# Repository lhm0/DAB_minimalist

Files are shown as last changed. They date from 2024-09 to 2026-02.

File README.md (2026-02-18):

# Minimalist DAB+ radio for the visually impaired

## Abstract: 
An easy to use DAB+ radio for the visually impaired. The radio is configured once using an intuitive web interface. Key components of the device are an Arduino D1 R32 microprocessor board and a DABshield board for radio reception. The radio is very easy to replicate. Full documentation is available on GitHub.

<p align="center"> 
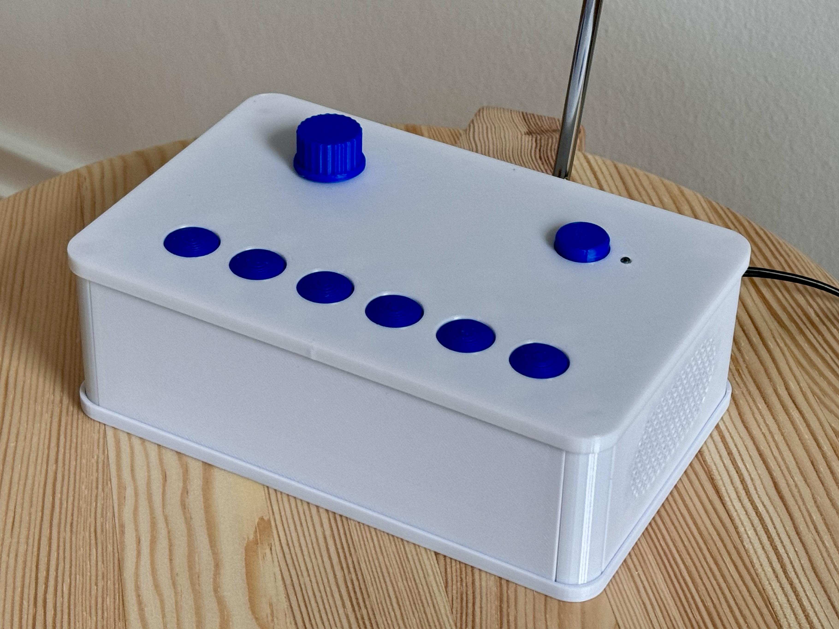
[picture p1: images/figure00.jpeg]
  
</p>

<p align="center"> 
<a href="https://youtu.be/GW8XSlcxrfo" target="_blank">
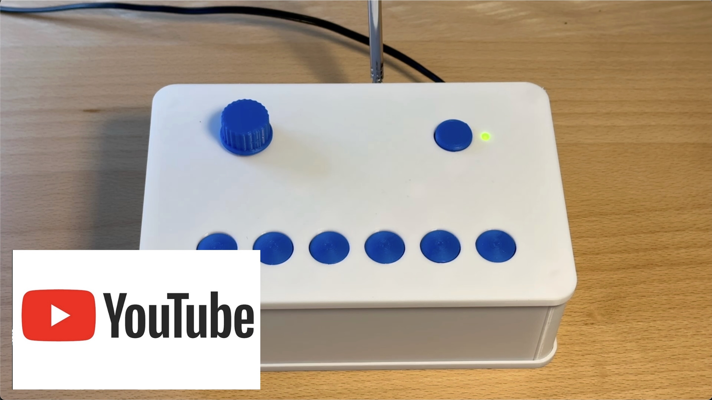
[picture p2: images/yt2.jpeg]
  
</a>
</p> 

## Part of an Accessible Devices Collection

This repository is part of a small collection of **minimalistic, accessibility-focused devices for visually impaired users**. All projects follow a similar philosophy: simple operation, tactile or acoustic feedback, and a strong focus on usability and low power consumption.

The currently available devices in this collection are:

- **[DAB+ Radio](https://github.com/lhm0/DAB_minimalist)** – This project: a minimalist, easy-to-use DAB+ radio  
- **[Talking Clock](https://github.com/lhm0/talking_clock)** – A clock that announces the time acoustically  
- **[Accessible IR Remote Control](https://github.com/lhm0/accessible_ir_remote)** – A tactile, low-power TV remote control  

All projects are designed to be practical, easy to reproduce, and suitable for everyday use by visually impaired users.

## 1. The idea
The radio was developed for a elderly visually impaired lady. The idea was to make the device as easy to use as possible. The preferred radio stations were to be selected once from the large number of DAB+ stations and assigned to 6 station buttons. In addition to these buttons, the on/off switch and the volume control should also be easy to reach with large buttons. A display has been omitted.

<p align="center"> 
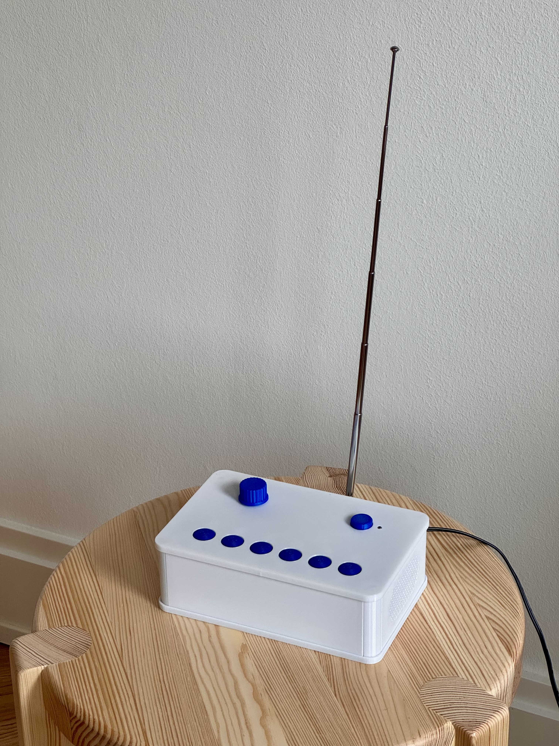
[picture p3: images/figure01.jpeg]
  
</p>

**Figure 1:  Minimalist DAB+ radio.** An easy to use DAB+ radio (not only) for visually impaired.

## 2. Description of the device

Digital Audio Broadcasting (DAB) is a digital radio standard being used predominatly in Europe, but also in Australia, and in parts of Africa and Asia [(Wikipedia)](https://en.wikipedia.org/wiki/Digital_Audio_Broadcasting).

The described radio is based on the DAB+ module [“DABshield”](https://www.dabshield.com), which is controlled by an Arduino microcontroller board “D1 R32”. It has the UNO form factor and can interface with UNO shields. The ESP32 microcontroller monitors 6 station buttons and the volume control. It also has a WiFi module for remote control of the radio.

The radio is housed in a 3D-printed housing (**figure 2**). All mechanical parts were designed with Fusion 360. The electronics are mounted on a carrier PCB (KiCAD). The microcontroller module and the “DABshield” are plugged on top of each other. The switches for the control of the device are also soldered onto the carrier board. This makes the radio easy and uncomplicated to replicate.

<p align="center"> 
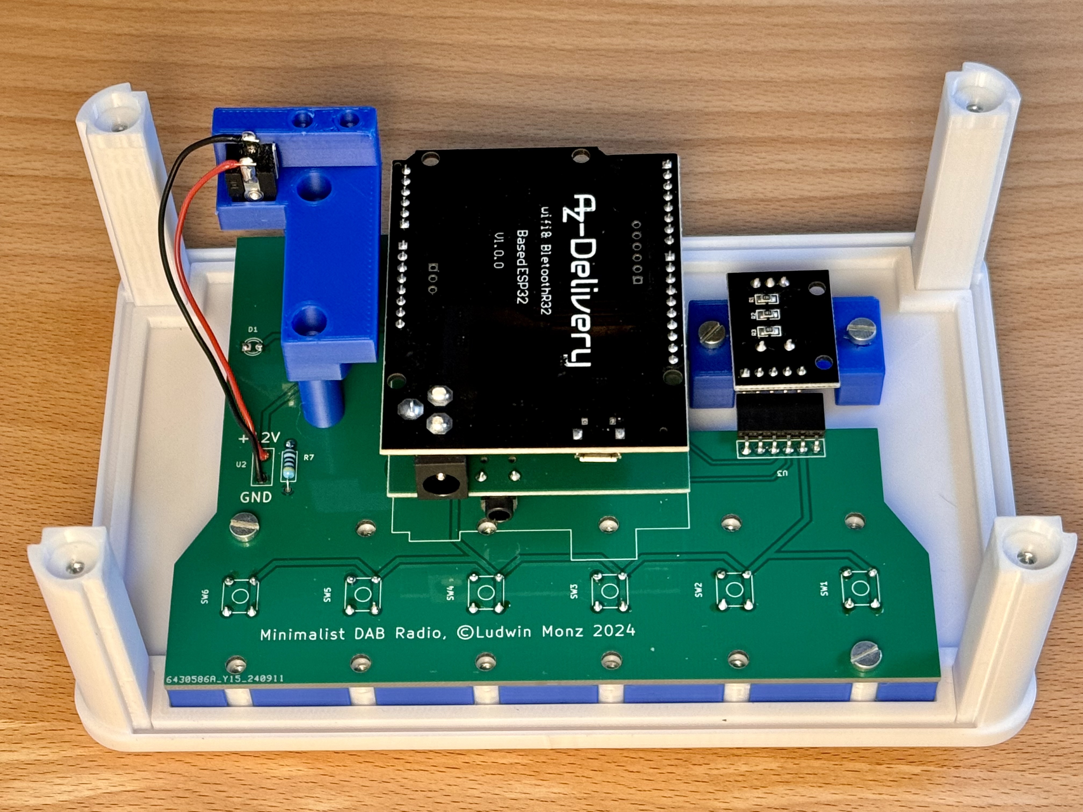
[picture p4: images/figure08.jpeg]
  
</p>
<p align="center"> 
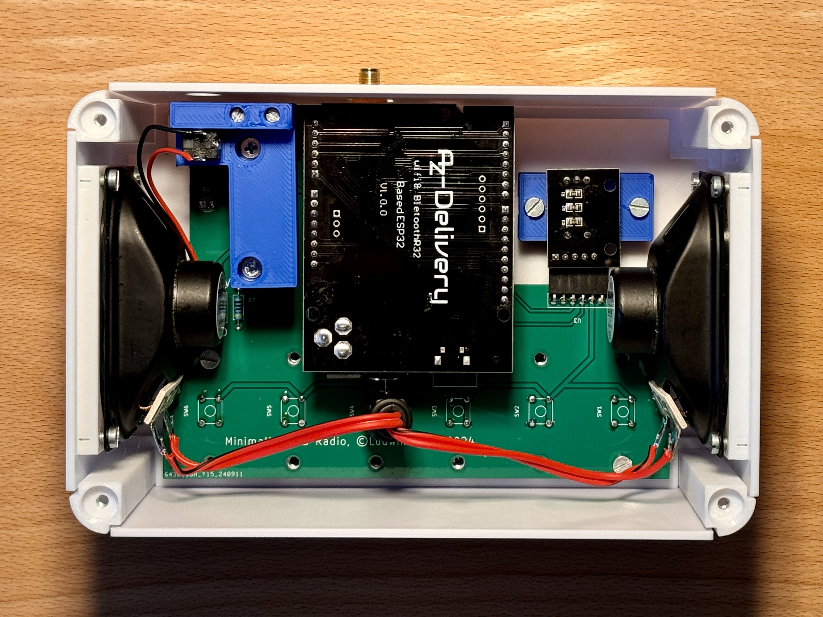
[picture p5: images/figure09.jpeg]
  
</p>

**Figure 2:  Mechnical setup of the radio.** The top cover serves as chassis of the device. All electronics components are connected through a carrier PCB.

## 3. Operation of the Device and initial setup

The user interface has been reduced to a minimum. In addition to the on/off switch and a volume control, it only consists of 6 station buttons. As the radio is intended for the visually impaired, the haptics of the controls are important.

All settings of the radio, i.e. the programming of the station buttons, the selected station and the volume, are stored in the flash memory of the microcontroller. They are immediately available when the device is switched on.

To program the station buttons in the initial setup, the device is connected to a cell phone or computer via a WiFi connection. If no connection data (SSID and password) of a WiFi network has been stored, the device switches to “Access Point Mode” when it is switched on. In this operating mode, a WiFi network with the SSID “mini_DAB” is created. You can connect to this network without using a password. The user interface is called up with a web browser by entering the address “192.168.4.1” in the address field of the browser.

<p align="center"> 
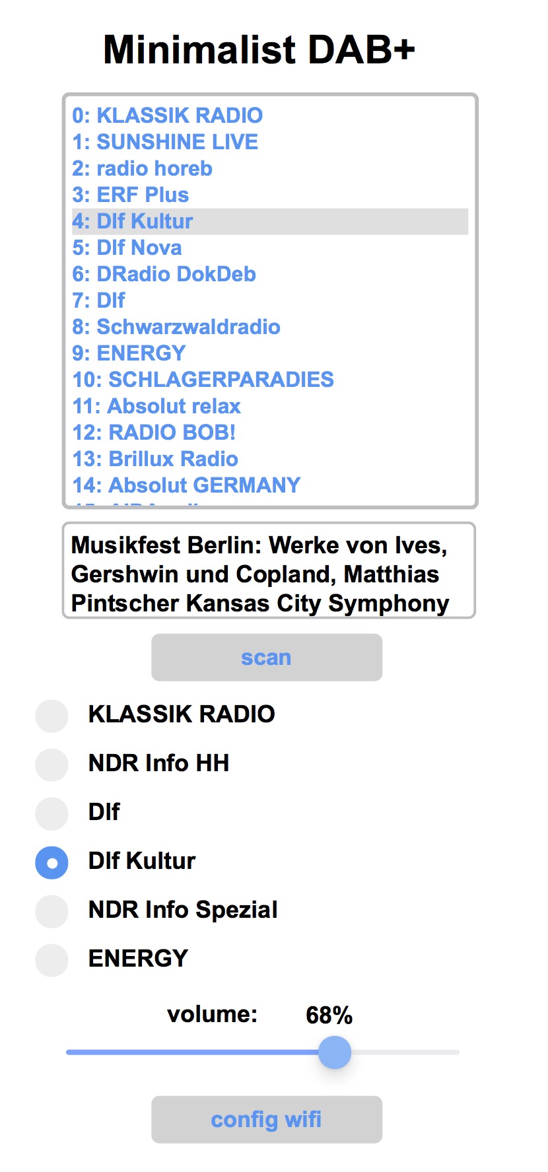
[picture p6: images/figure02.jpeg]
  
</p>

**Figure 3:** The **web user interface** allows for device configuration.

The setup screen displays a scrollable list of available DAB+ radio stations. If you select an entry, the radio tunes to the station. Below the station list, the continuous text information of the selected station is displayed.

If the location of the radio has been changed, it is advisable to start a new station search. To do this, click on the corresponding button. The saved station list and the selected assignment of the station buttons will then be deleted. The new station list is automatically saved in the flash memory.

There are 6 assignable station buttons further down. These correspond to the 6 physical buttons on the radio. To assign a station to the buttons, first select it in the station list. Then click and hold on one of the station buttons. The station is then saved for this button.
The volume can also be changed via the website.

As soon as you leave the setup page, the radio works independently with the preset parameters.

## 4. Replicating the radio
All housing parts are 3D printed (**figure 4**). The design data and STL files are available in the GitHub repository. M2 and M3 nuts are inserted into some parts for the mechanical connection of the parts. To insert the nuts, the 3D print must be paused at the correct point in time (**figure5**).

<p align="center"> 
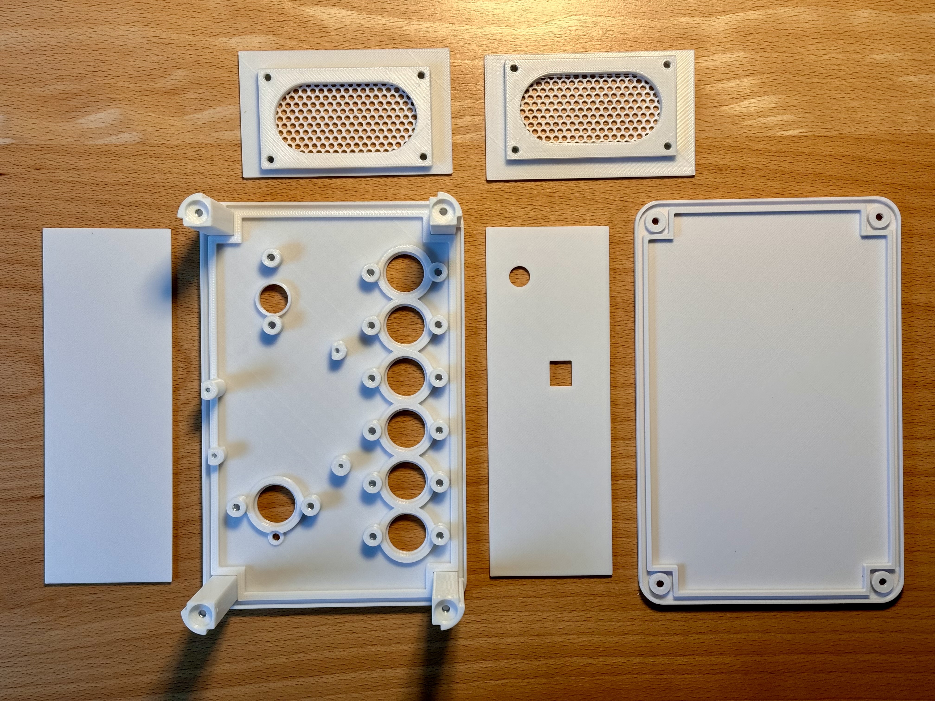
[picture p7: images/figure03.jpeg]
  
</p>
<p align="center"> 
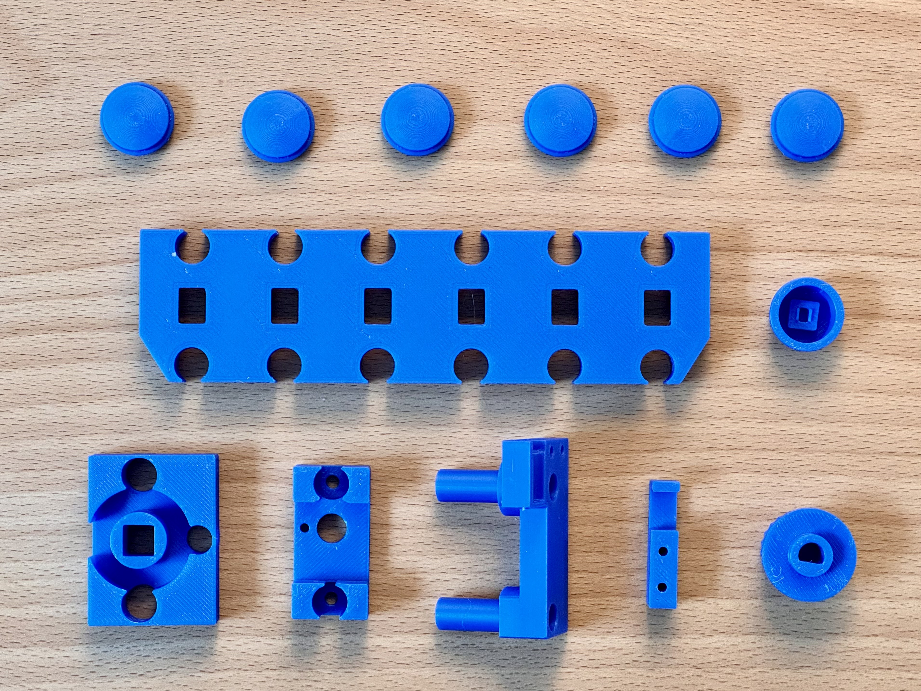
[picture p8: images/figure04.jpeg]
  
</p>

**Figure 4: Mechanical parts of the Minimalist DAB+ Radio.** All parts are 3D printed.

<p align="center"> 
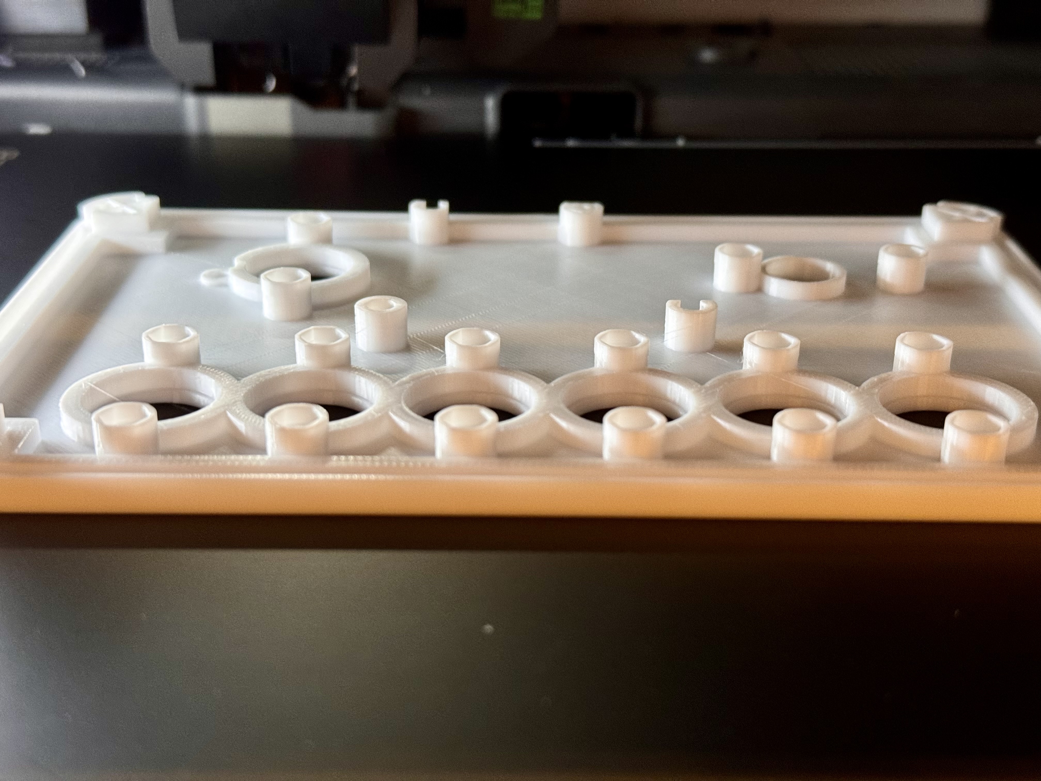
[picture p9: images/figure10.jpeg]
  
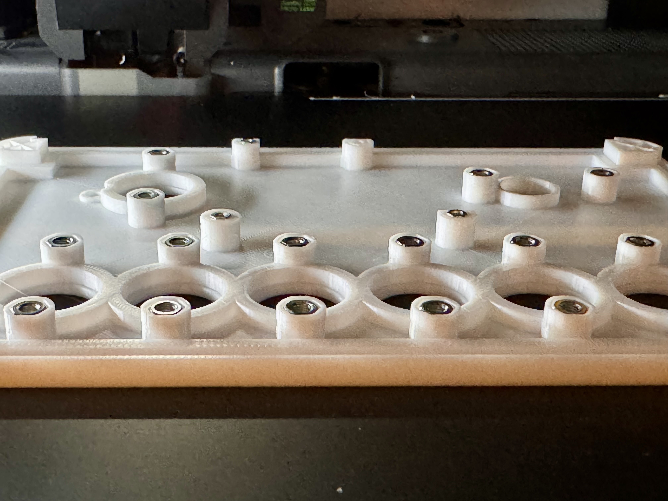
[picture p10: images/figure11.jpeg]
  
</p>

**Figure 5: M2 and M3 nuts need to be inserted into the 3D print**

The electronic components are off-the-shelf (**figure 6**). They are listed in the parts list. The only "single source component" is the DAB+ radio module 'DABshield', developed and marketed by the UK company AVIT Research Ltd. [(50 GBP + shipping and handling).](https://www.dabshield.com/store) This module is very reliable and easy to interface with and use.

The carrier board was designed with KiCAD. The project files including the production files are available in the GitHub repository. For the prototype, the board was manufactured by JLCPCB - however, there are numerous alternatives that offer very good quality for relatively little money.

<p align="center"> 
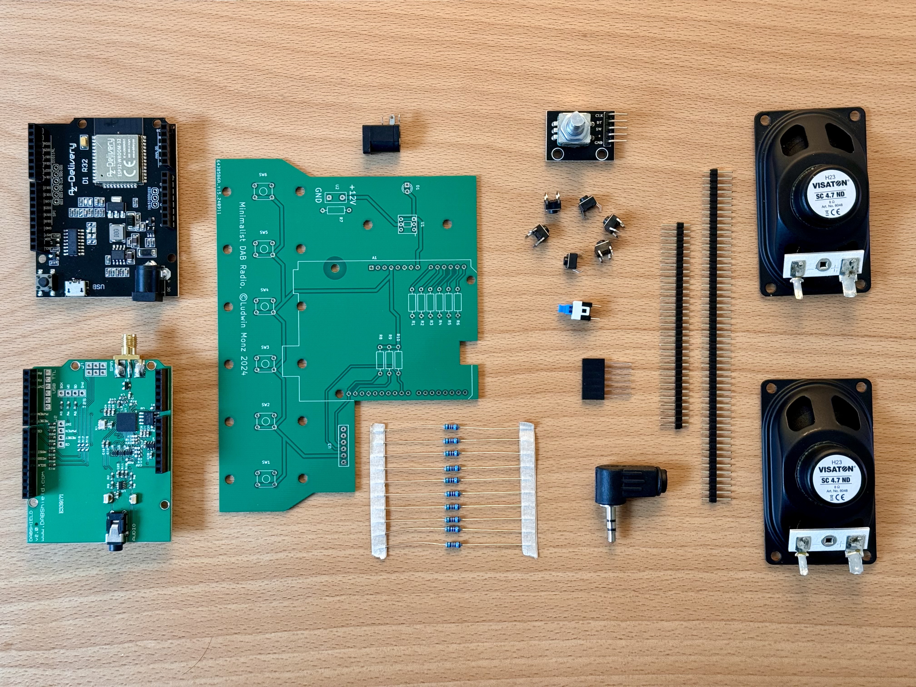
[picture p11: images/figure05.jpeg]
  
</p>

**Figure 6: The electronics components of the DAB+ Radio**

It is best to start assembling the device by fitting the carrier board. The switch, buttons and LED are mounted on the back of the board. The pin headers for connecting the DABshield and the microcontroller are positioned on the component side. The details can be found in the KiCAD design files. **Figure 7** shows the front and back of the board .

<p align="center"> 
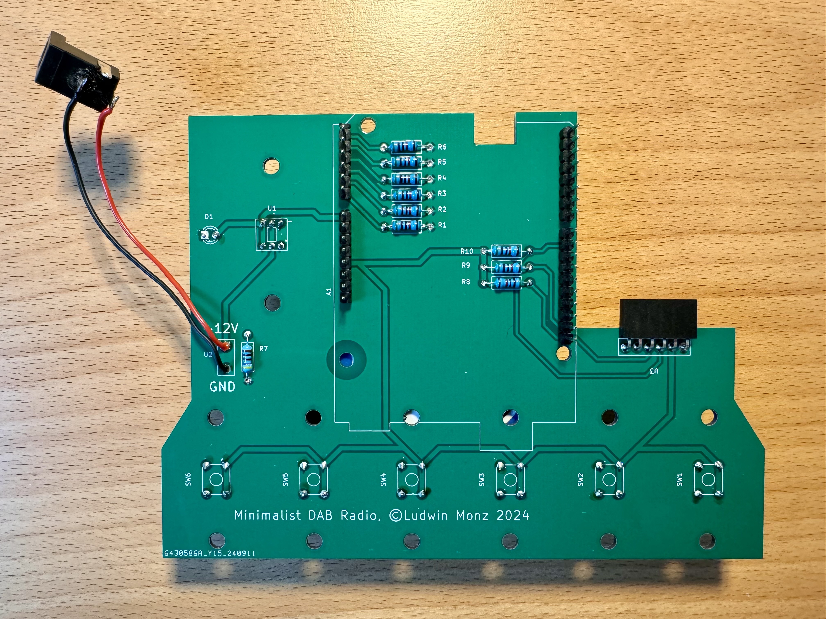
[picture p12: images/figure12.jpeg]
  
</p><p align="center"> 
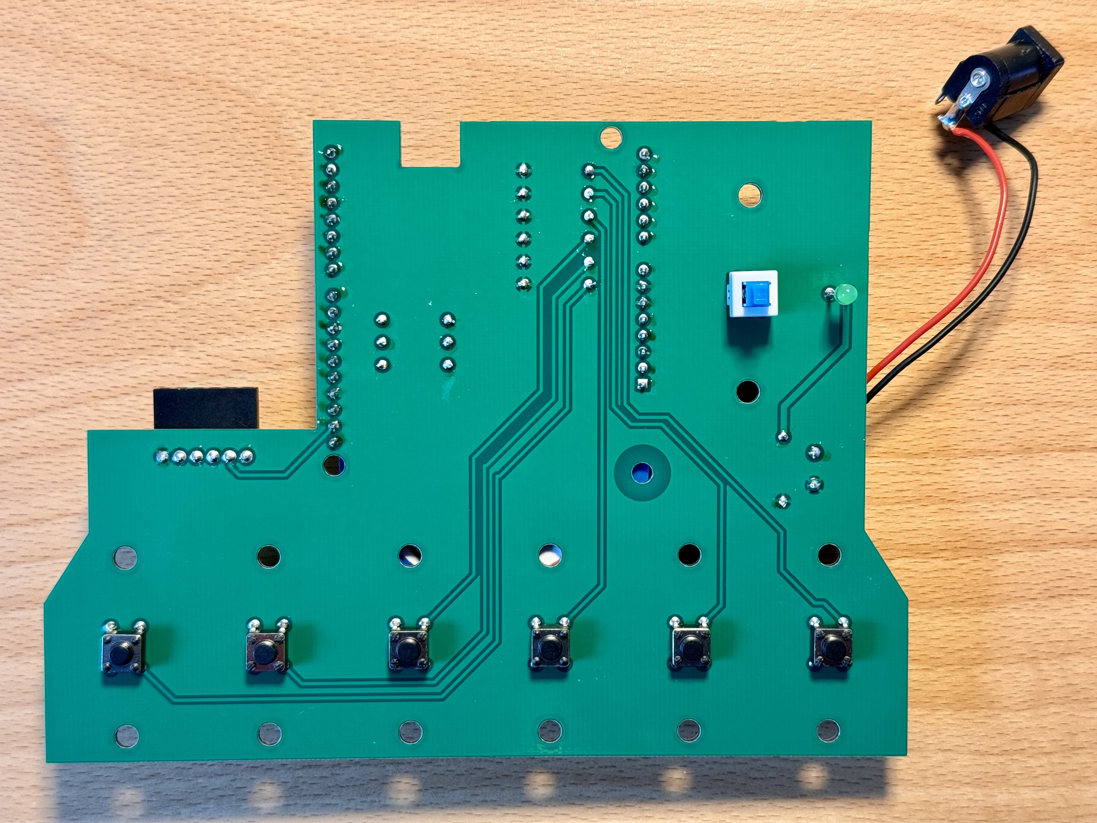
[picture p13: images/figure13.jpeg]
  
</p>

**Figure 7: Carrier PCB.** All switches and buttons are soldered to the back side, pin headers for the DABshield are on the component side.

The encoder for the volume setting is mounted on a carrier block. Note the correct position of the 5 pins of the module in the 6-pin socket (**figure 8**).

<p align="center"> 
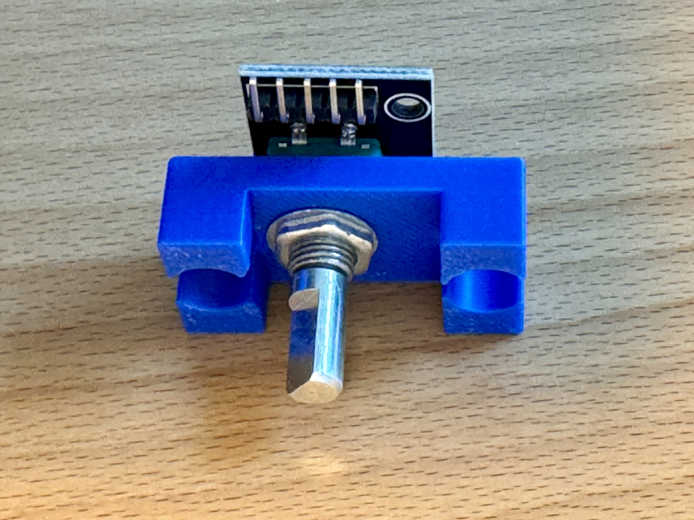
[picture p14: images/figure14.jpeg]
  
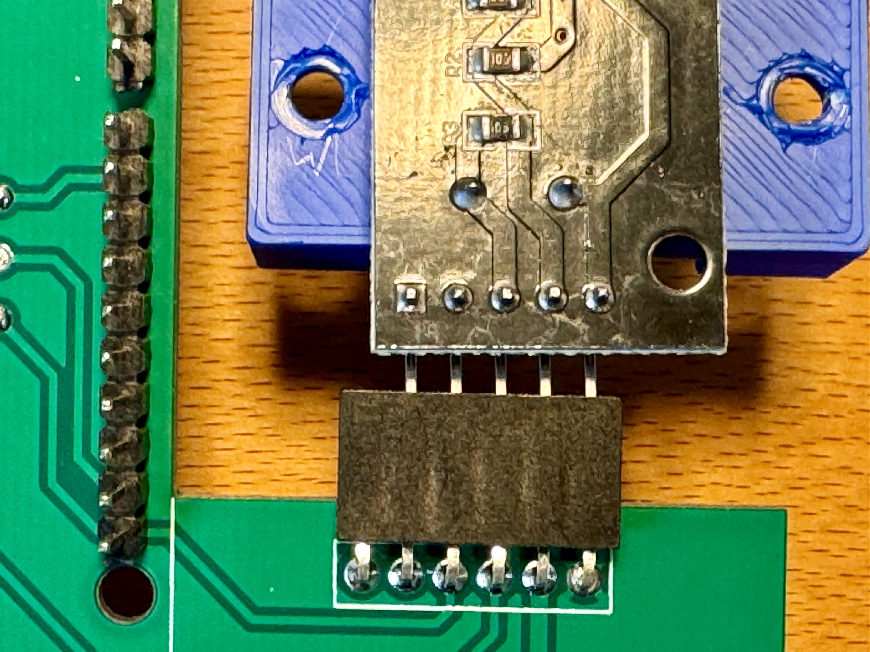
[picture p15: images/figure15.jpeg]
  
</p>

**Figure 8: Mounting of the encoder for volume control**

The two speakers are connected with a 3.5 mm jack plug. The common pole of the plug is the negative pole (**figure 9**).

<p align="center"> 
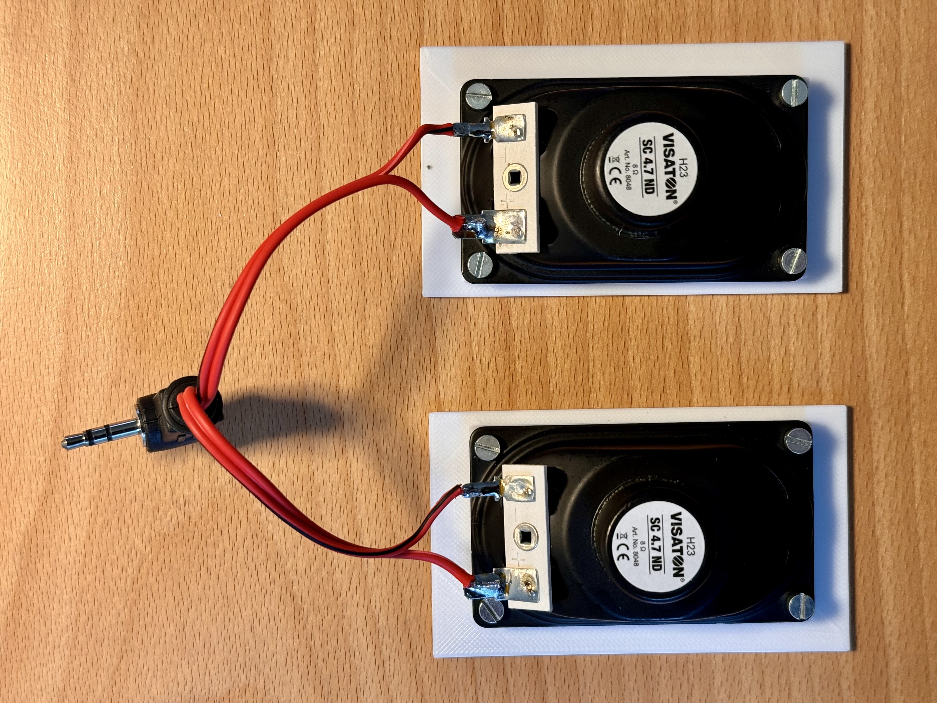
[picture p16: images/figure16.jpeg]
  
</p>

**Figure 9: Two speakers are connected to a 3.5 mm jack plug**

The successive steps for assembling the appliance are shown in Figure 10. The front cover can initially be removed to allow access to the micro-USB socket of the microcontroller module. In this way, the software can be loaded onto the module.

<p align="center"> 
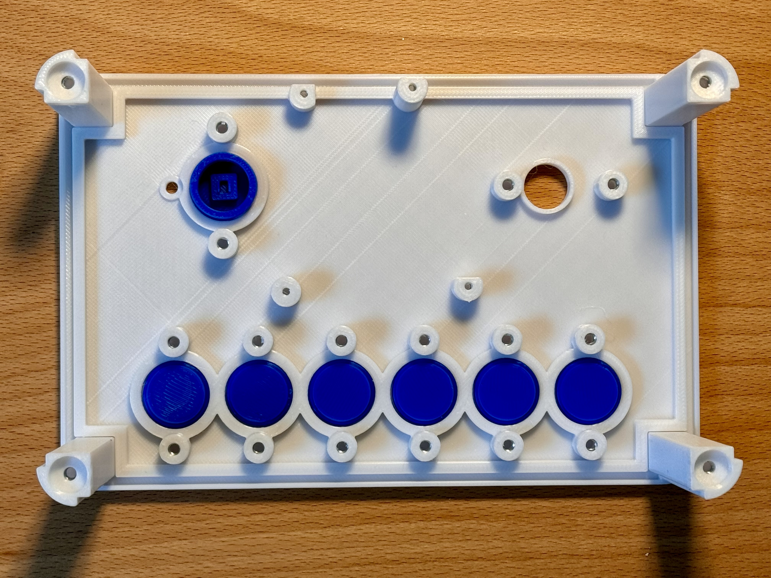
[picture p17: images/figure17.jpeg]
  
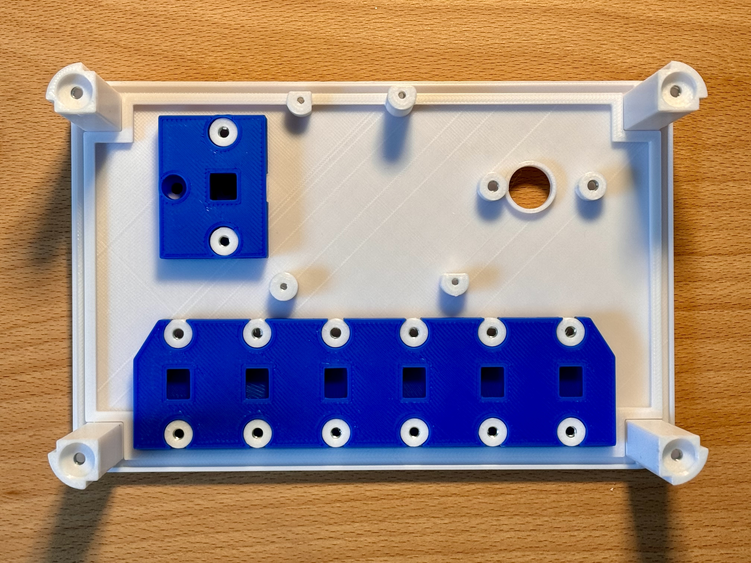
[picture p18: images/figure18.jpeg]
  
</p>
<p align="center"> 
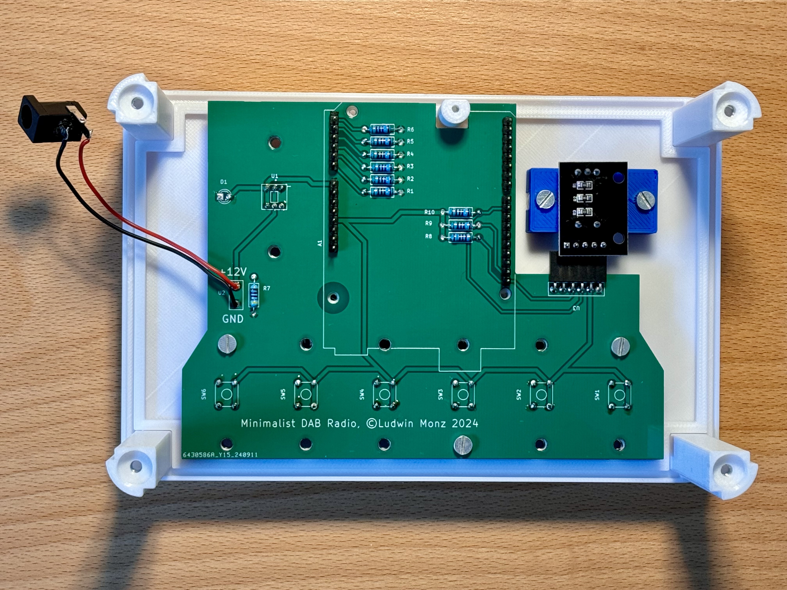
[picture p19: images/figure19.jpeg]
  
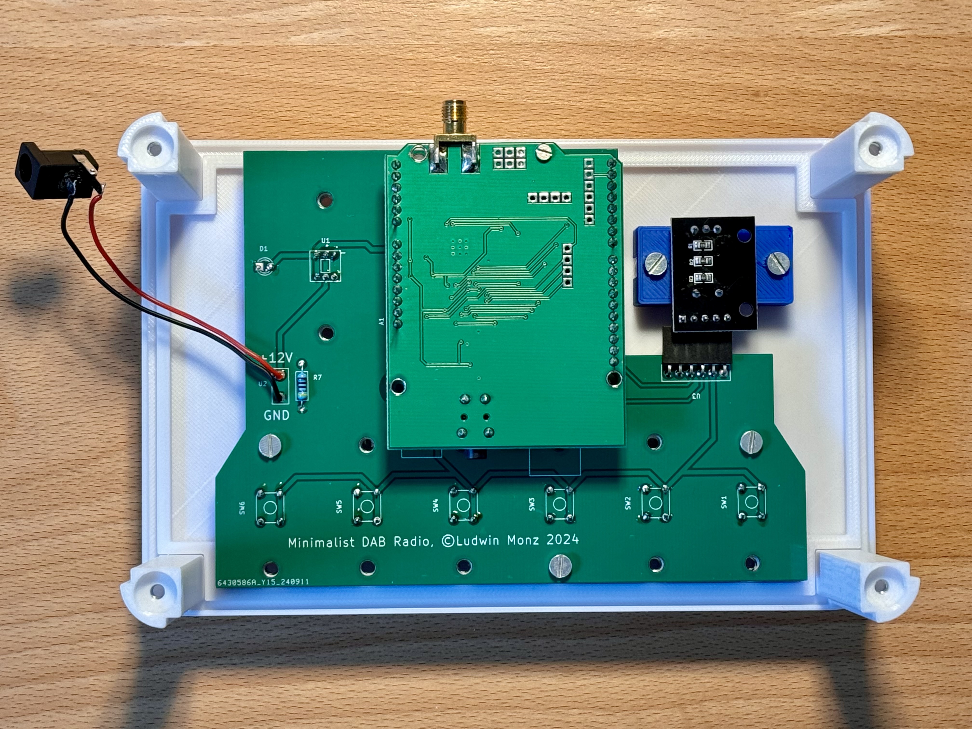
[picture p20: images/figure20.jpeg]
  
</p>
<p align="center"> 
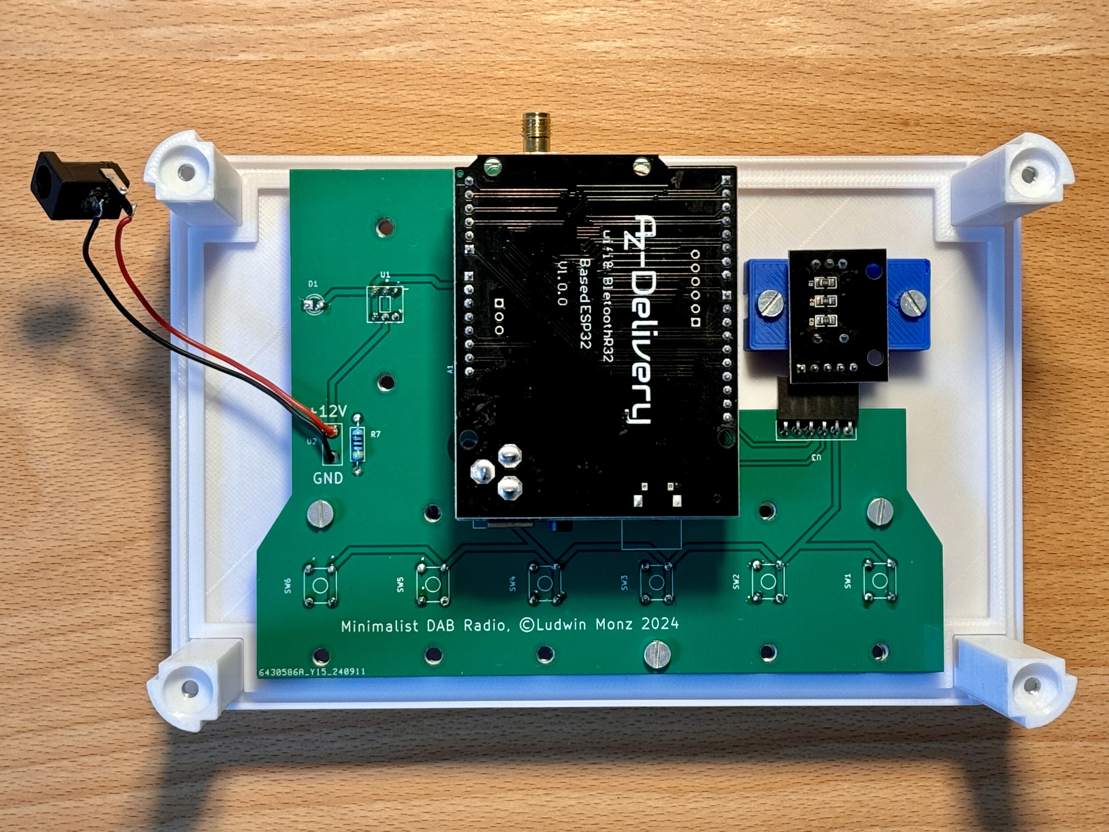
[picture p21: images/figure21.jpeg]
  
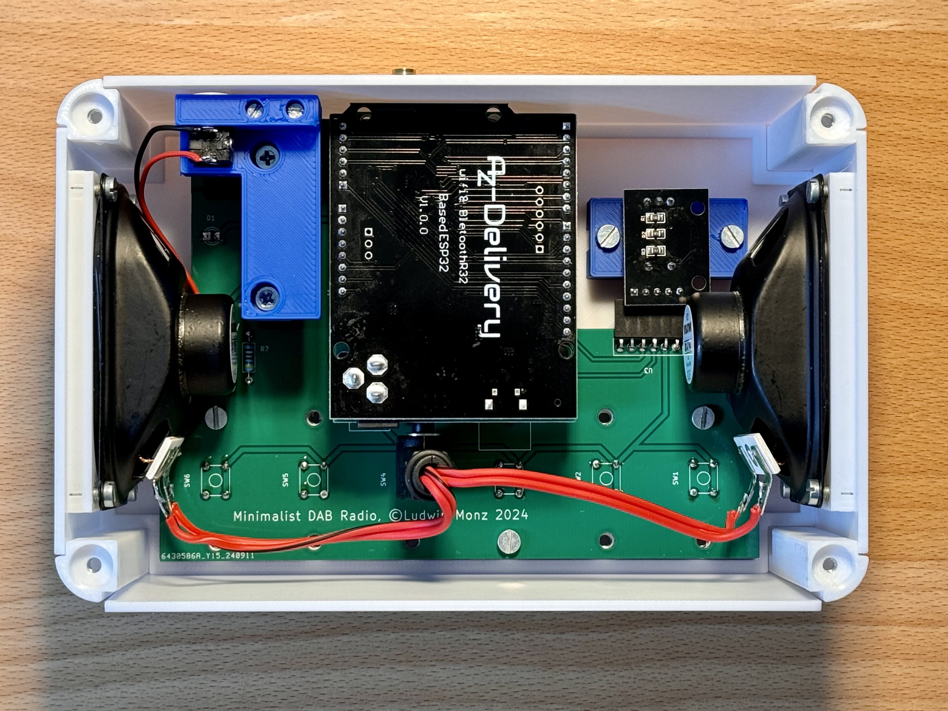
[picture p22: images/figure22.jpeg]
  
</p>

**Figure 10: Successive steps for assembling the DAB+ radio**

## 5. Uploading the software
Although the Arduino IDE could also do the job, I prefer using Visual Studio Code with the platformIO extension. If you do not know this environment, please note, that there are numerous tutorials on Visual Studio Code and platformIO on youTube.

In order to install the software on the DAB+ radio's microcontroller, download a copy of the github repository and store it on your computer, locally. Open the sub-folder “software” in Visual Studio Code (**figure 11**). As all configuration data including the necessary libraries is included in the platformIO.ini file, no further configuration of the software is needed. Connect the Arduino R32 of the radio to your computer using a micro-USB cable. Start the compilation and the data transfer with the check button of the platformIO extension. The program will notify, when the process is completed.

<p align="center"> 
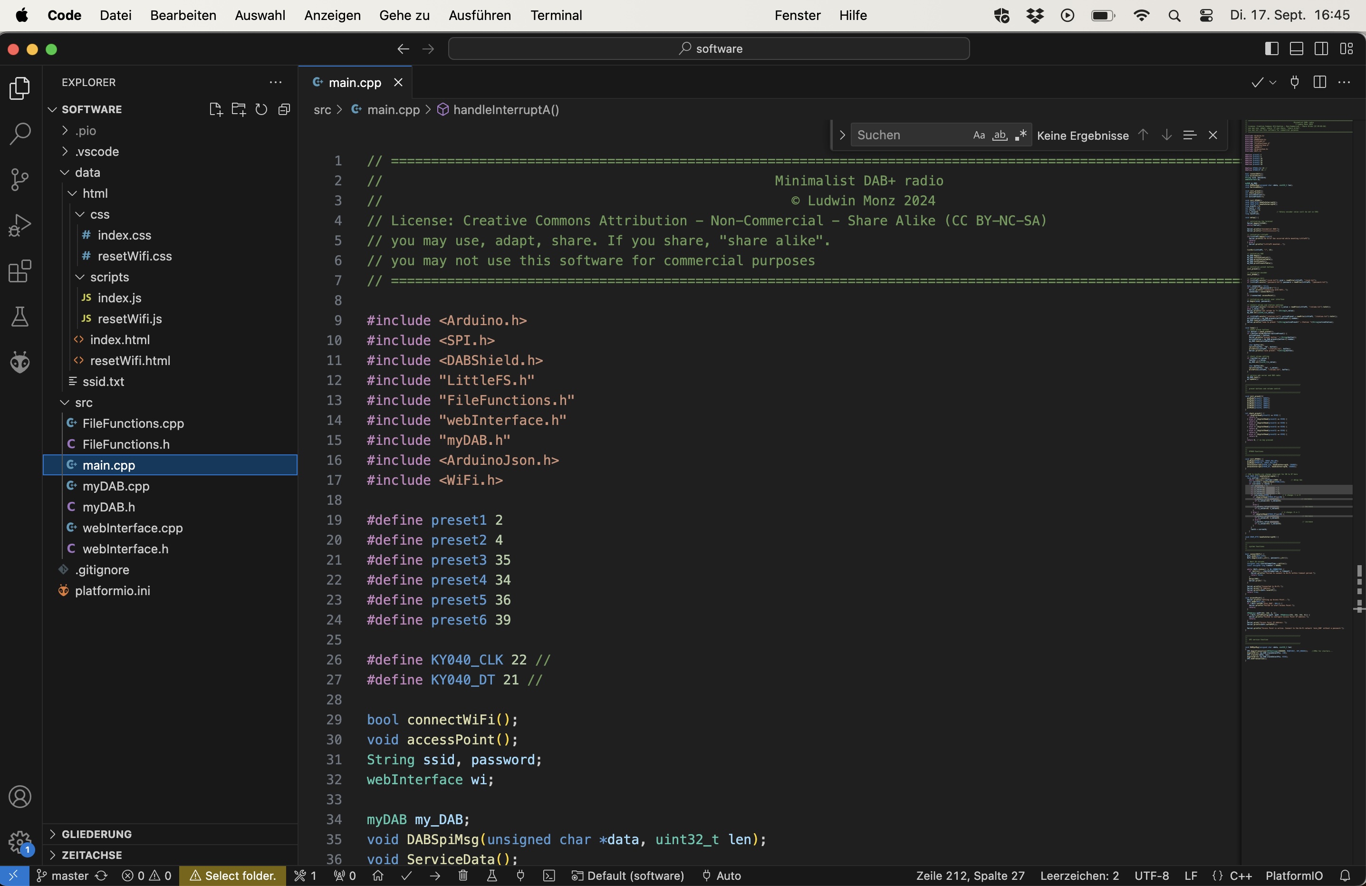
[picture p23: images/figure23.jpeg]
  
</p>

**Figure 11: Visual Studio Code and platformIO**

However, the software uses a flash disk ("LittleFS"), which includes all web page data (HTML, JS, and CSS files). This data is included in the "data" subfolder of "software". In order to upload the filesystem to the controller, click on the platformIO icon (see picture, click #1) (**figure 12**). Then, click on “Build Filesystem Image” (click #2) to generate the image for the flash disk. Finally, upload the image to the microcontroller with the “Upload Filesystem Image” button (click #3). If the computer does not connect to the microcontroller, it might help to re-sart VS Code.

<p align="center"> 
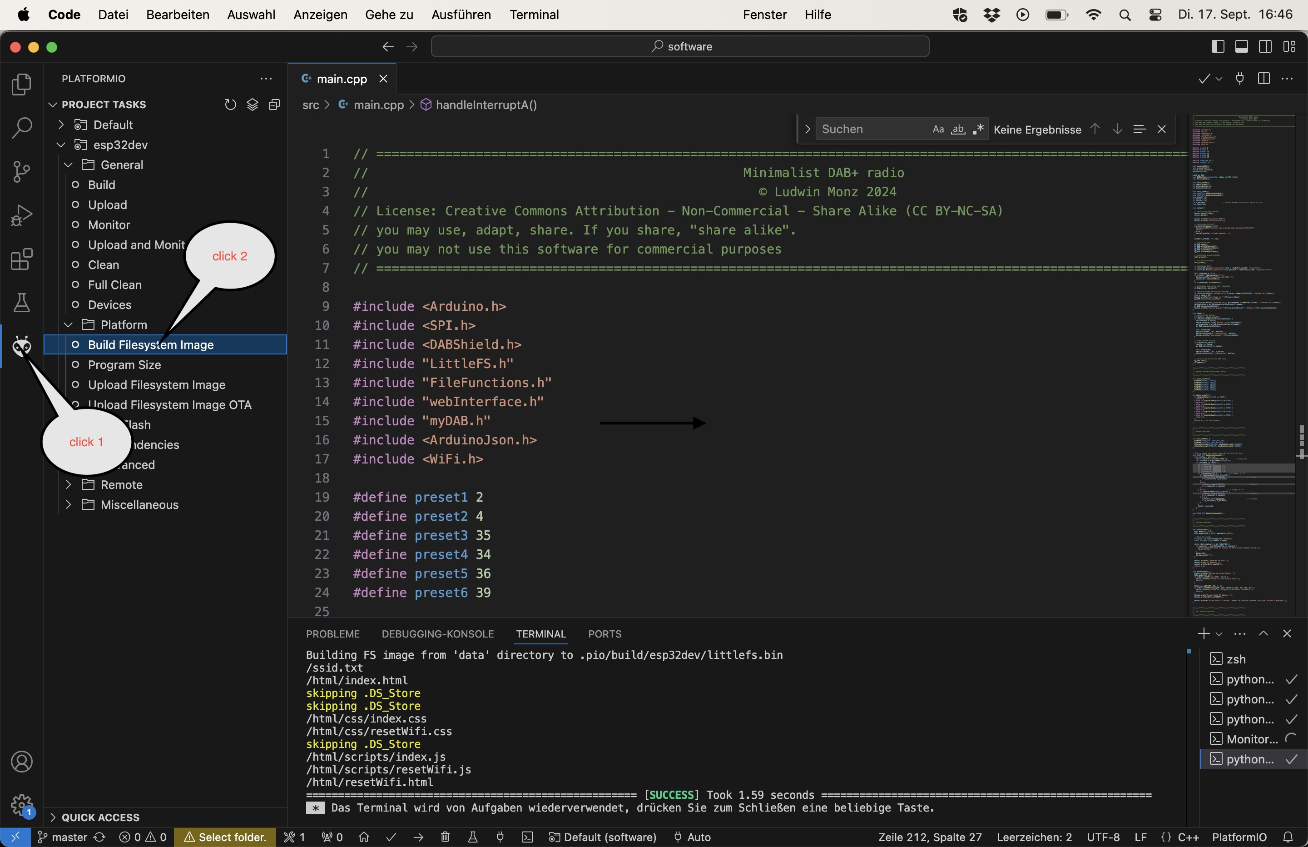
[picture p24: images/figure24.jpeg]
  
</p>
<p align="center"> 
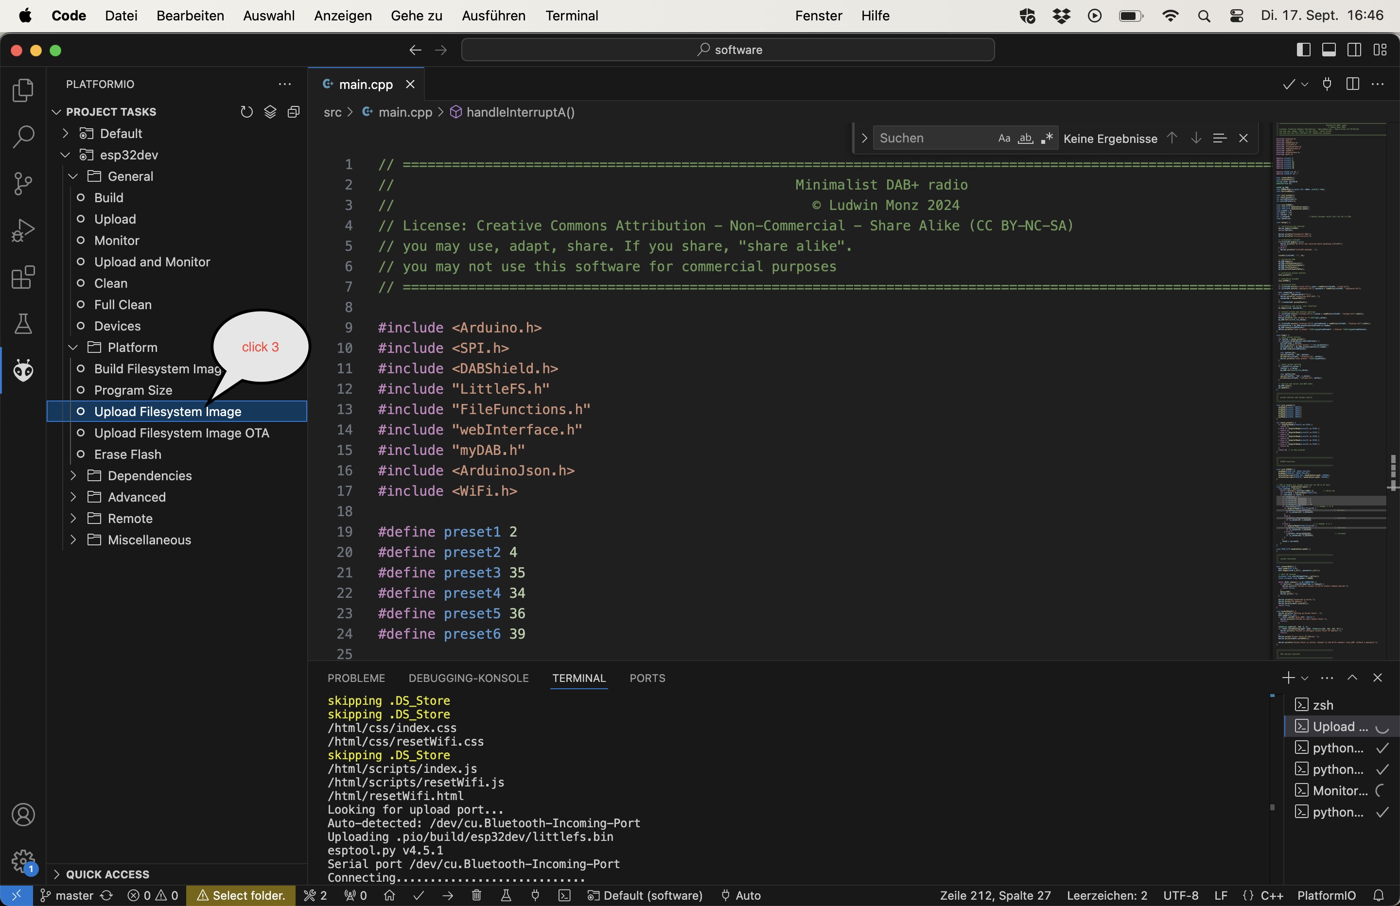
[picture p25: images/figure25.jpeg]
  
</p>

**Figure 12: Uploading the filesystem**

## 6. Conclusions

The minimalist DAB+ radio was developed as an easy-to-use device for the visually impaired. The complexity of the user interface, which is caused by the large variety of DAB+ stations and the wide range of functions of the standard in most devices, was deliberately avoided. A web interface was implemented for setting up the device, which enables the user to conveniently select the desired stations and assign the station buttons.

The radio uses an Arduino microcontroller. The entire software is available for further development and modification. The device is easy to replicate. All mechanical components are 3D-printed. The electronics consist of a carrier board onto which the components are soldered.

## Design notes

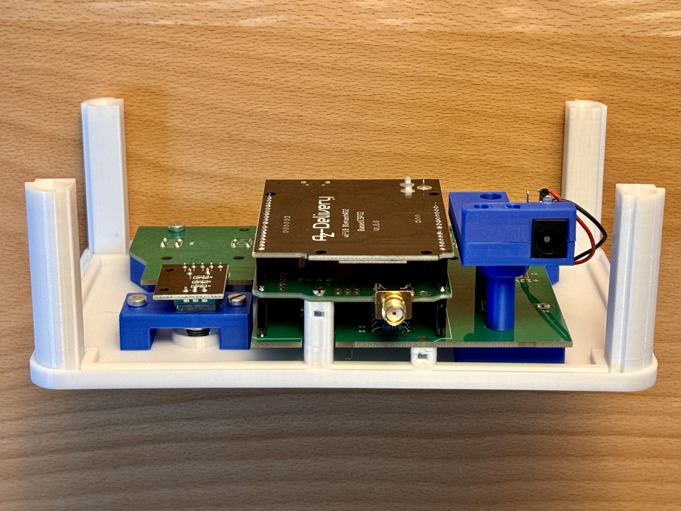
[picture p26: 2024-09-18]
images/figure07.jpeg

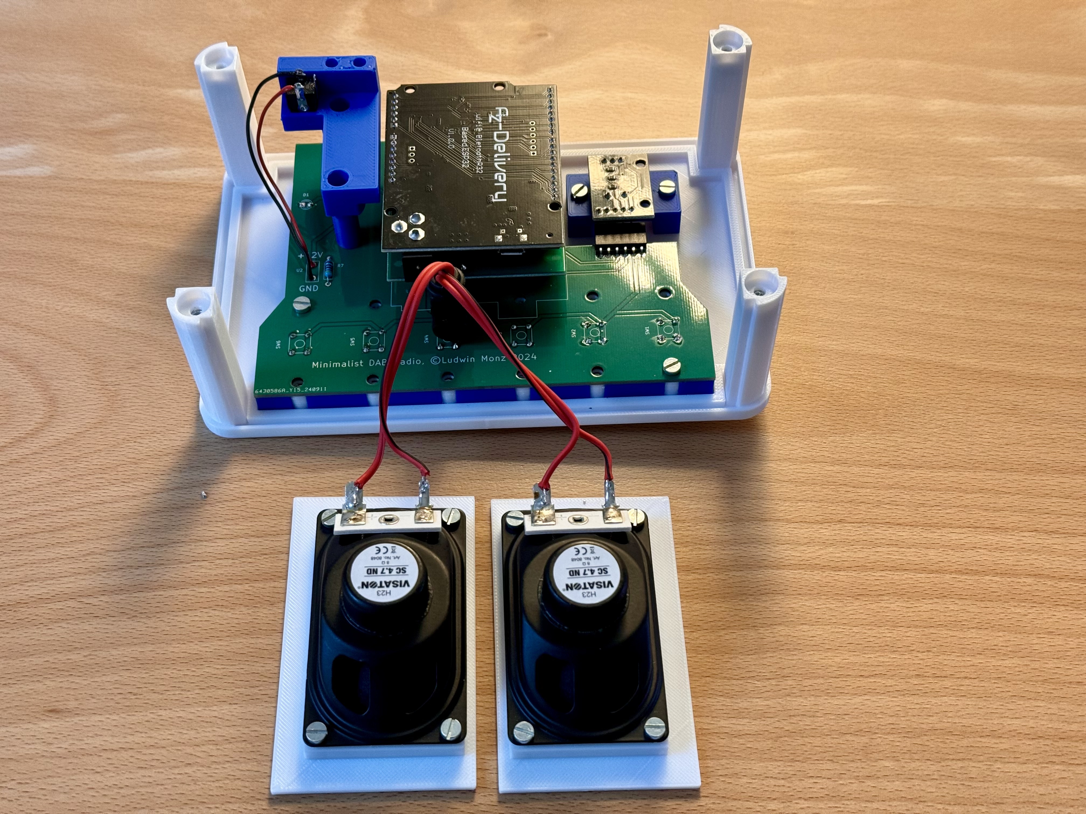
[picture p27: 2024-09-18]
images/figure06.jpeg

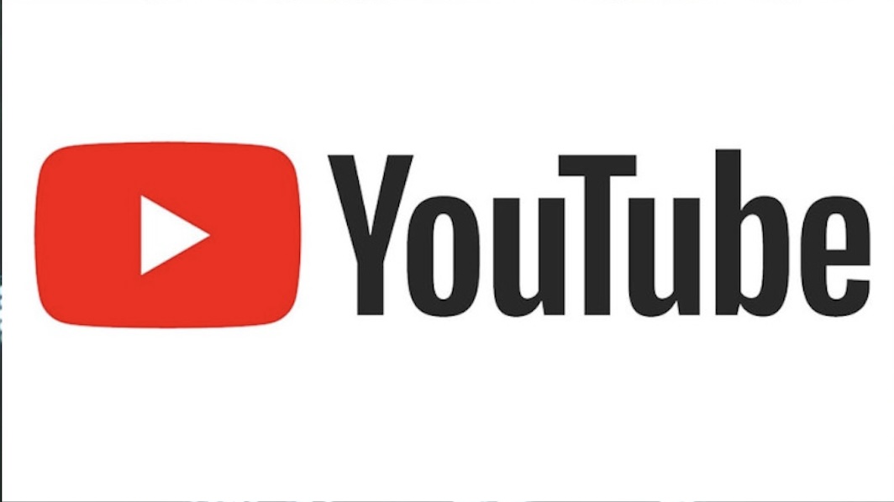
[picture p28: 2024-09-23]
images/yt.jpeg

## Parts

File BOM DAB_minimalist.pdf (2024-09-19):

# BOM Minimalist DAB+ Radio

Item # | number | Description | supplier link | price per unit total
1 | 1 Arduino D1 R32 | https://www.az-delivery.de/products/esp32-d1-r32-board | 10,99 € | 10,99 €
2 | 1 DABshield | https://www.dabshield.com/store | 60,00 € | 60,00 €
3 | 1 carrier pcb: custom made according to Gerber files | https://jlcpcb.com | 9,00 € | 9,00 €
4 | 1 DC Power Jack | https://www.digikey.de/short/zhjwnm5b | 0,55 € | 0,55 €
5 | 9 Resistor 47k | generic | 0,10 € | 0,90 €
6 | 1 Resistor 470 | generic | 0,10 € | 0,10 €
7 | 1 Encoder KY040 | https://www.az-delivery.de/products/drehimpulsgeber-modul | 4,29 € | 4,29 €
8 | 6 Omron BSF1020, tactile switch, 6x6mm, 5mm height | https://www.digikey.de/short/pr2q5z7f | 0,34 € | 2,04 €
9 | 1 PUSHBUTTON SWITCH, TL2230 | https://www.digikey.de/short/v70b7f8n | 0,76 € | 0,76 €
10 | 1 stackable header, 6 pins | https://www.digikey.de/short/dwnpzmhh | 1,57 € | 1,57 €
11 | 1 audio plug, 3.5 mm | https://www.digikey.de/short/c0dpz4hr | 1,22 € | 1,22 €
12 | 2 pin header, 50 pins, 2.54mm | generic | 2,00 € | 4,00 €
13 | 2 loudspeaker | https://www.digikey.de/short/b51nzdzv | 7,69 € | 15,38 €

110,80 €

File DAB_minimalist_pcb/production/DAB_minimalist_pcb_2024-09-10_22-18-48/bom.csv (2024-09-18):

Designator | Footprint | Quantity | Value | LCSC Part #
A1 | Arduino_D1_R32 | 1 | Arduino_D1_R32
D1 | LED_D3.0mm_sym | 1 | LED
R1, R10, R2, R3, R4, R5, R6, R8, R9 | R_Axial_DIN0207_L6.3mm_D2.5mm_P10.16mm_Horizontal | 9 | 47k
R7 | R_Axial_DIN0207_L6.3mm_D2.5mm_P10.16mm_Horizontal | 1 | 1k
SW1, SW2, SW3, SW4, SW5, SW6 | OmronTasterSym | 6 | SW_Push
U1 | SW_Push_2x2 | 1 | switch2x2
U2 | connector_2pin_breit | 1 | 12V in
U3 | connector_6pin | 1 | KY040 encoder

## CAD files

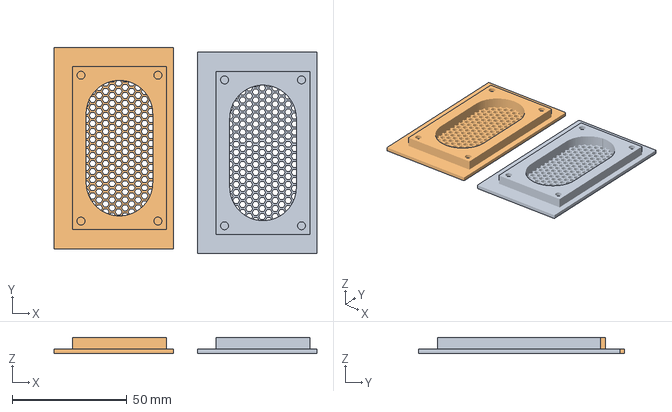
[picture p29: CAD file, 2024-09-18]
3D_prints/cover_side v6.3mf
114.5 x 89.9 x 7.00 mm
speaker_cover v6.stl x 2

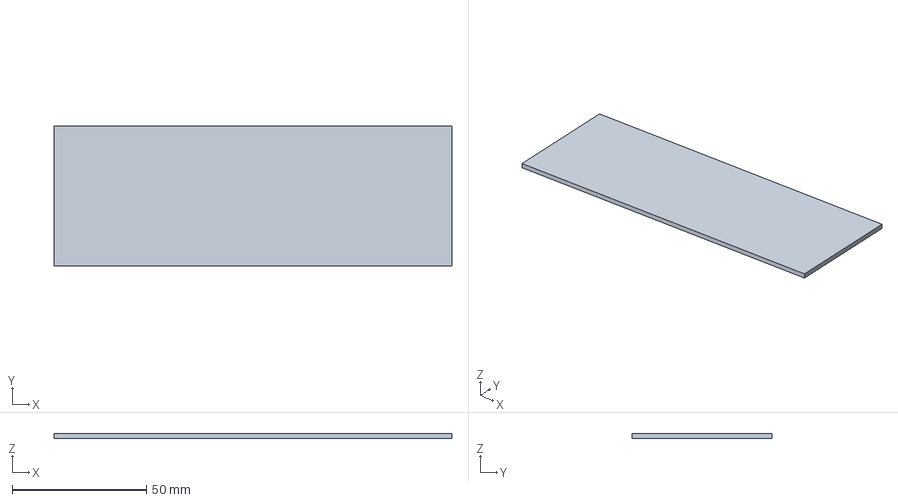
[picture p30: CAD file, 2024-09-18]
3D_prints/cover_front v1.3mf
148.0 x 52.0 x 2.00 mm

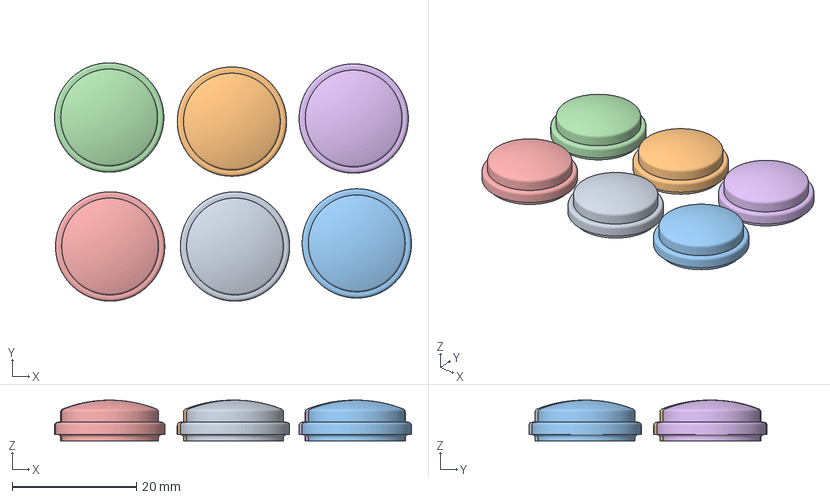
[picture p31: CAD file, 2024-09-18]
3D_prints/Druckknopf v5.3mf
57.4 x 38.4 x 6.56 mm
Druckknopf v5.stl x 6

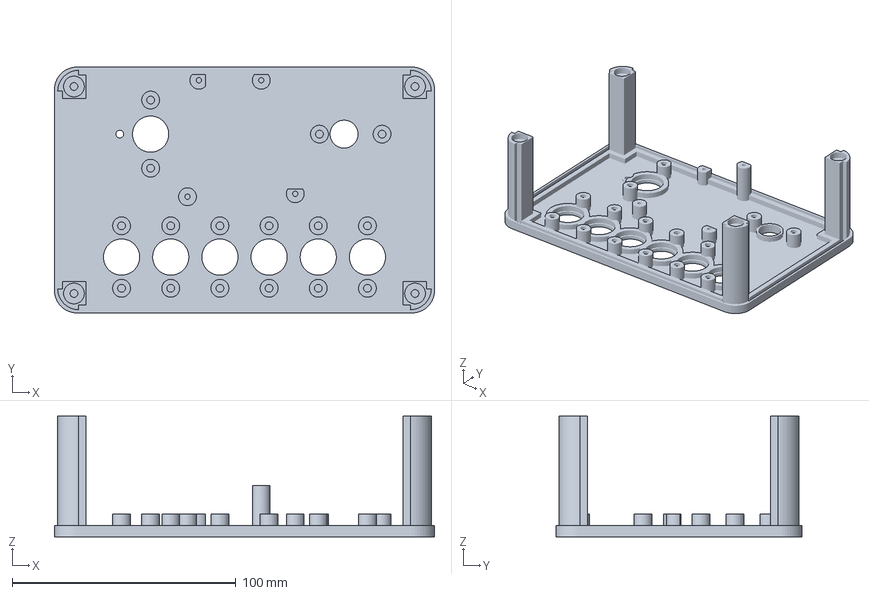
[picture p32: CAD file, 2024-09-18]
3D_prints/Cover_top v19 final.3mf
170.0 x 110.0 x 54.0 mm

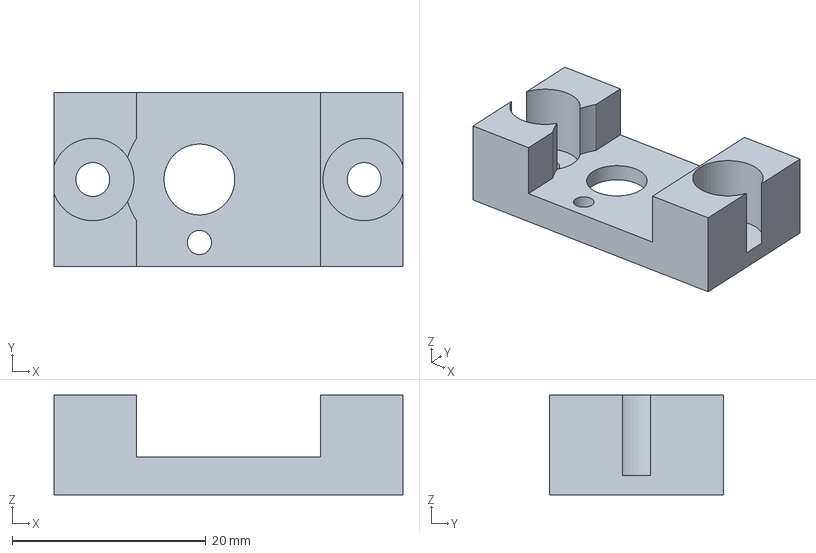
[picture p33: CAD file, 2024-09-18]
3D_prints/Encoder_block v4.3mf
36.0 x 18.0 x 10.3 mm

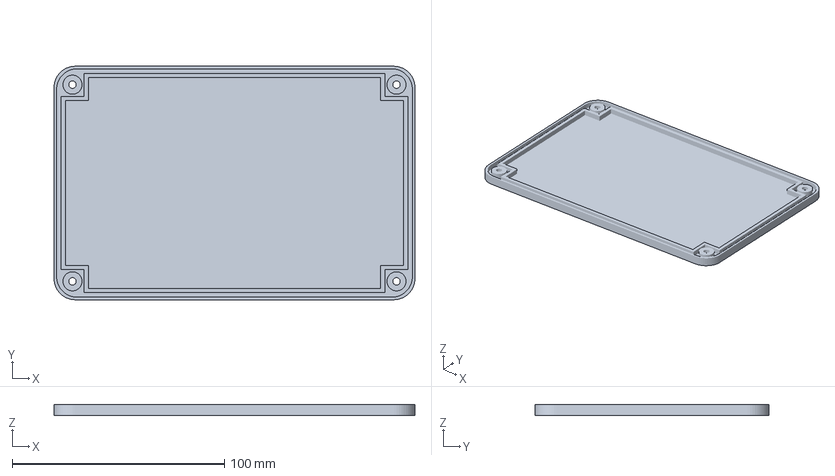
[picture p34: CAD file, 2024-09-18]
3D_prints/cover_bottom v1.3mf
170.0 x 110.0 x 5.00 mm

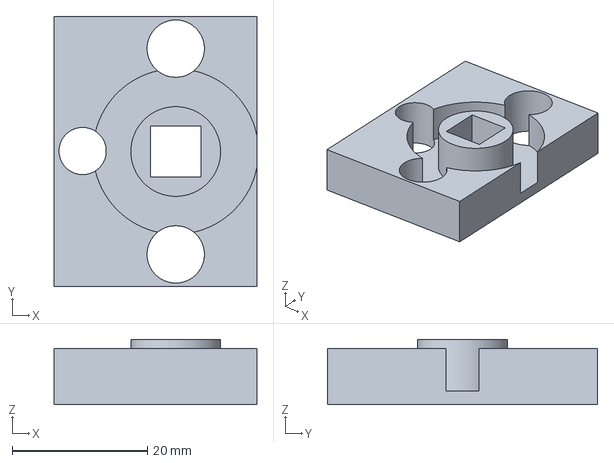
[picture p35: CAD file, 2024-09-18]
3D_prints/on_off_block v3.3mf
30.0 x 40.0 x 9.70 mm

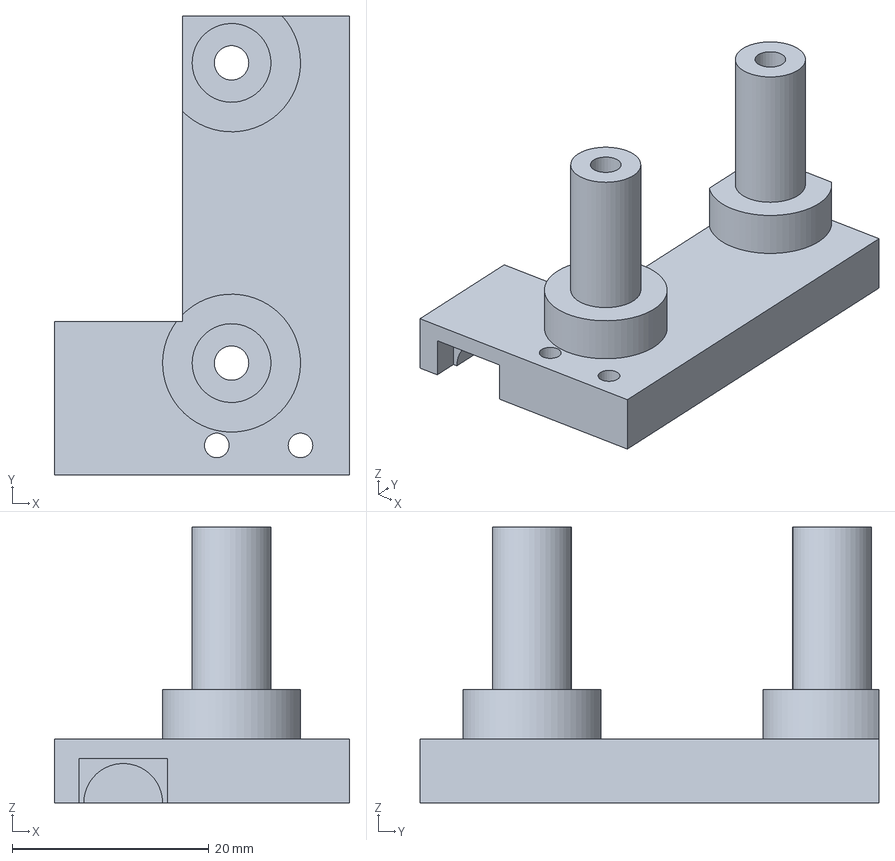
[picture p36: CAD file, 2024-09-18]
3D_prints/power_tray v7.3mf
30.0 x 46.6 x 28.0 mm

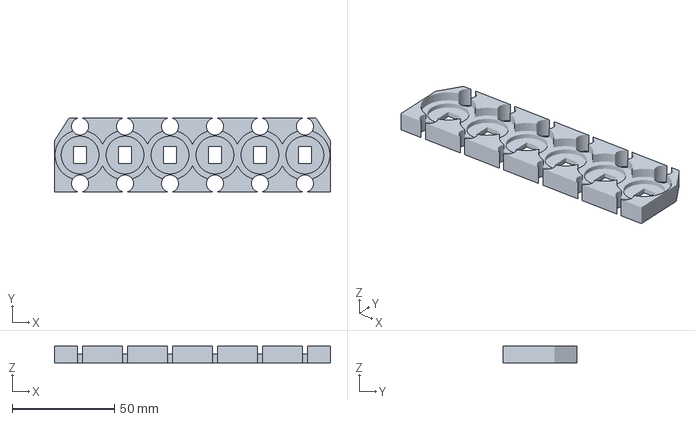
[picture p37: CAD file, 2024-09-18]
3D_prints/preset_block v6.3mf
135.0 x 36.0 x 8.30 mm

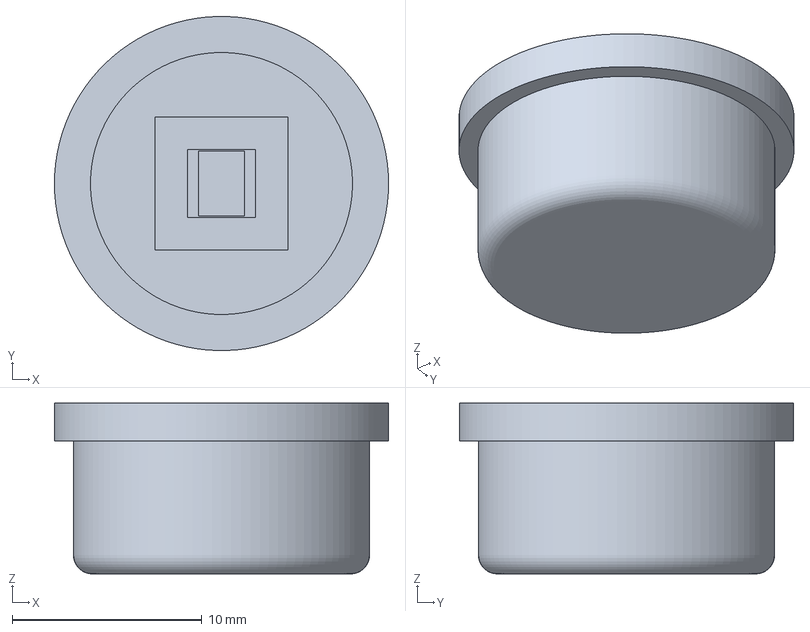
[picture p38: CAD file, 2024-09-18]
3D_prints/on_off_switch v6.3mf
17.6 x 17.6 x 9.00 mm

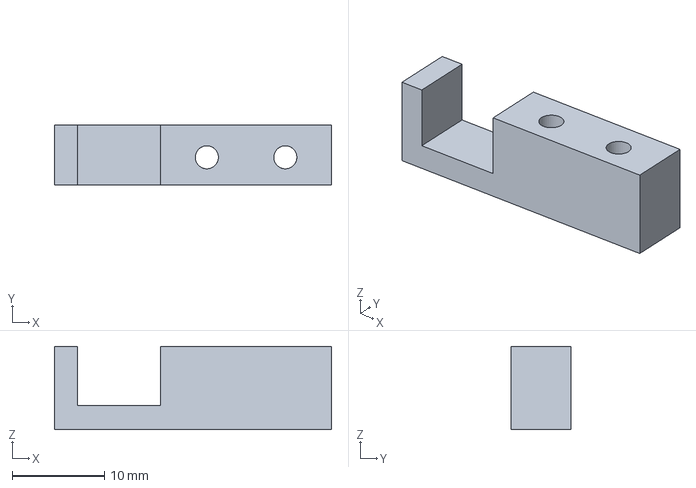
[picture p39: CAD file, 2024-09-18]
3D_prints/Power_plug_holder v3.3mf
30.0 x 6.50 x 9.00 mm

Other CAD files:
3D_prints/cover_back v3.3mf
3D_prints/Cover_top v19 final.f3d
3D_prints/Cover_top v19 final.stl
3D_prints/Druckknopf v5.f3d
3D_prints/Druckknopf v5.stl
3D_prints/Encoder_block v4.f3d
3D_prints/Encoder_block v4.stl
3D_prints/Power_plug_holder v3.f3d
3D_prints/Power_plug_holder v3.stl
3D_prints/cover_back v3.f3d
3D_prints/cover_back v3.stl
3D_prints/cover_bottom v1.f3d
3D_prints/cover_bottom v1.stl
3D_prints/cover_front v1.f3d
3D_prints/cover_front v1.stl
3D_prints/cover_side v6.f3d
3D_prints/cover_side v6.stl
3D_prints/on_off_block v3.f3d
3D_prints/on_off_block v3.stl
3D_prints/on_off_switch v6.f3d
3D_prints/on_off_switch v6.stl
3D_prints/power_tray v7.f3d
3D_prints/power_tray v7.stl
3D_prints/preset_block v6.f3d
3D_prints/preset_block v6.stl

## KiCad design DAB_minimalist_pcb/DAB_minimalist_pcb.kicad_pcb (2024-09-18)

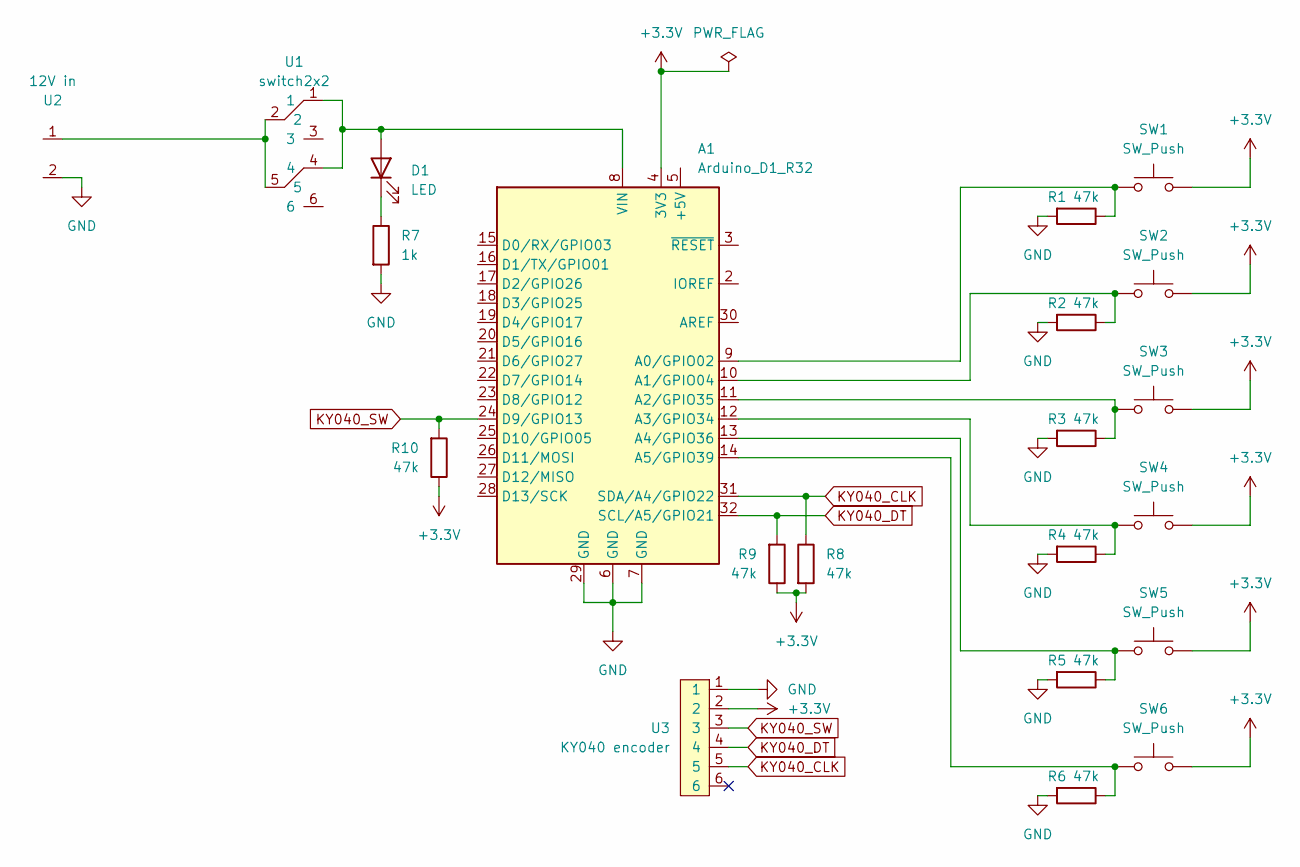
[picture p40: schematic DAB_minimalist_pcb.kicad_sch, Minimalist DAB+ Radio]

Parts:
A1: Arduino_D1_R32
D1: LED; LED_D3.0mm_sym
R1, R2, R3, R4, R5, R6, R8, R9, R10: 47k; R_Axial_DIN0207_L6.3mm_D2.5mm_P10.16mm_Horizontal
R7: 1k; R_Axial_DIN0207_L6.3mm_D2.5mm_P10.16mm_Horizontal
SW1, SW2, SW3, SW4, SW5, SW6: SW_Push; OmronTasterSym
U1: switch2x2; SW_Push_2x2
U2: 12V in; connector_2pin_breit
U3: KY040 encoder; connector_6pin

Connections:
+3.3V: A1.4 (3V3), R8.2, R9.1, R10.1, SW1.2, SW2.2, SW3.2, SW4.2, SW5.2, SW6.2, U3.2
GND: A1.6 (GND), A1.7 (GND), A1.29 (GND), R1.2, R2.2, R3.2, R4.2, R5.2, R6.2, R7.2, U2.2, U3.1
KY040_CLK: A1.31 (SDA/A4/GPIO22), R8.1, U3.5
KY040_DT: A1.32 (SCL/A5/GPIO21), R9.2, U3.4
KY040_SW: A1.24 (D9/GPIO13), R10.2, U3.3
unnamed: A1.9 (A0/GPIO02), R1.1, SW1.1
unnamed: A1.10 (A1/GPIO04), R2.1, SW2.1
unnamed: A1.11 (A2/GPIO35), R3.1, SW3.1
unnamed: A1.12 (A3/GPIO34), R4.1, SW4.1
unnamed: A1.13 (A4/GPIO36), R5.1, SW5.1
unnamed: A1.14 (A5/GPIO39), R6.1, SW6.1
unnamed: A1.8 (VIN), D1.2 (A), U1.1, U1.4
unnamed: D1.1 (K), R7.1
unnamed: U1.2, U1.5, U2.1

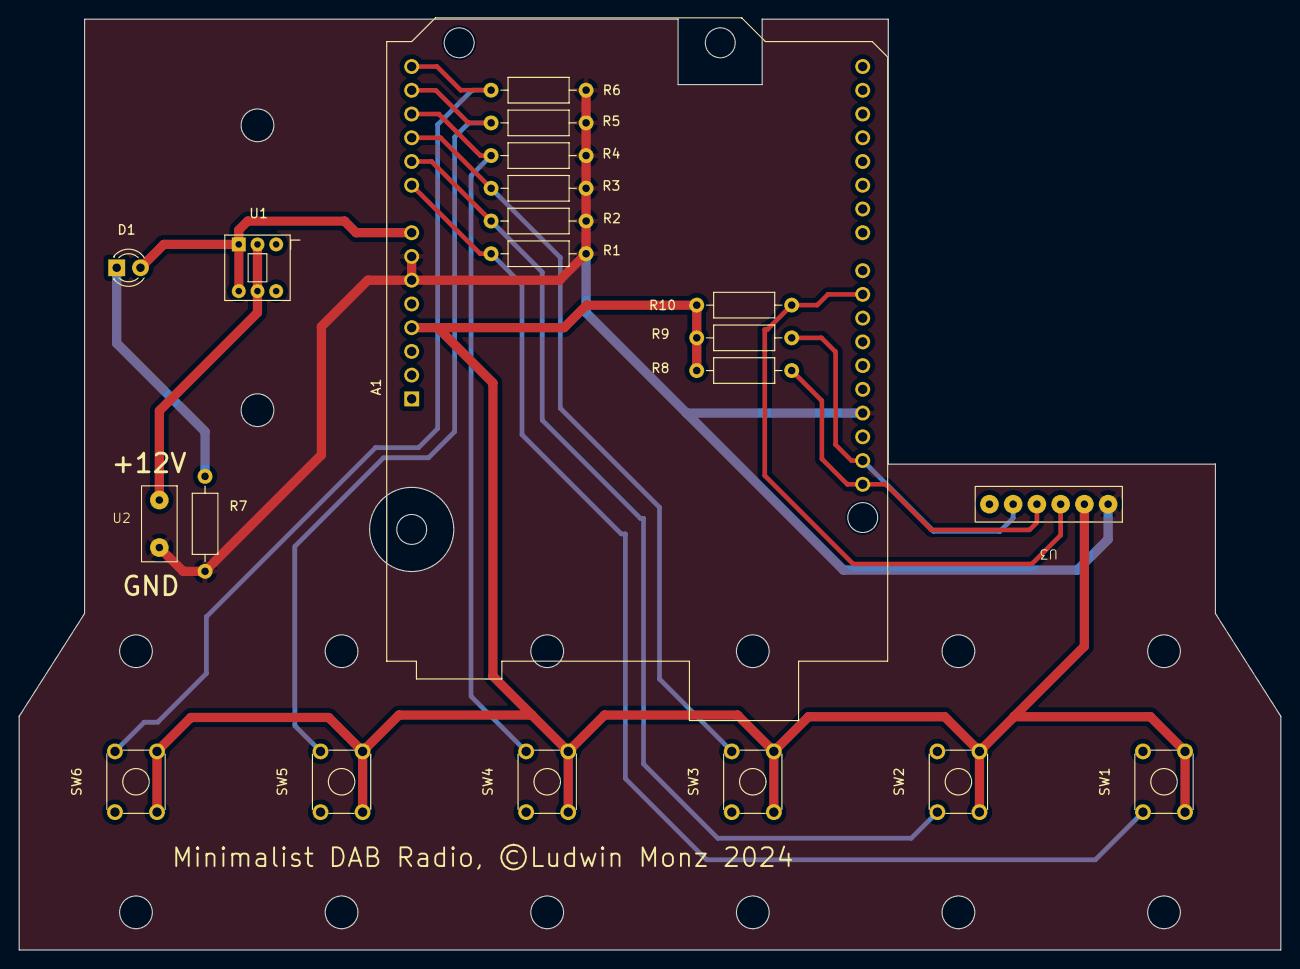
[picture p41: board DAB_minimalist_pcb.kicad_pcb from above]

Board: 2 copper layers, 135.0 x 99.6 mm, 21 parts (0 on the bottom side), 14 nets.

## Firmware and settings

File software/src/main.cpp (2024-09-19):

// =========================================================================================================================================
//                                                 Minimalist DAB+ radio
//                                                   © Ludwin Monz 2024
// License: Creative Commons Attribution - Non-Commercial - Share Alike (CC BY-NC-SA)
// you may use, adapt, share. If you share, "share alike".
// you may not use this software for commercial purposes 
// =========================================================================================================================================

//#define digitalVolume                // If "digitalVolume" is defined, the volume control will be active

#include <Arduino.h>
#include <SPI.h>
#include <DABShield.h>
#include "LittleFS.h"
#include "FileFunctions.h"
#include "webInterface.h"
#include "myDAB.h"
#include <ArduinoJson.h>
#include <WiFi.h>

#define preset1 2
#define preset2 4
#define preset3 35
#define preset4 34
#define preset5 36
#define preset6 39

#define KY040_CLK 22 // 
#define KY040_DT 21 // 

bool connectWiFi();
void accessPoint();
String ssid, password;
webInterface wi;

myDAB my_DAB;
void DABSpiMsg(unsigned char *data, uint32_t len);
void ServiceData();

void init_preset();
int check_preset();
int activeStation=-1;
int activePreset=-1;

void init_KY040();
void IRAM_ATTR handleInterruptA(); 
void IRAM_ATTR handleInterruptB(); 
long eventA = 0;
int lastA = LOW;
int lastVol = 0;
int v_value=0;                   // Rotary encoder value (will be set in ISR)
long lastPrint;

void setup() {

  // intitialise the terminal
  Serial.begin(112500);
  while(!Serial);

  Serial.println("minimalist DAB+"); 
  Serial.println("===============");
  
  // initialize LittleFS
  if(!LittleFS.begin(true)){
    Serial.println("An Error has occurred while mounting LittleFS");
    return;
  } else {
    Serial.println("LittleFS mounted...");
  }

  listDir(LittleFS, "/", 15);
  
  // initialize DAB
  my_DAB.begin();
  my_DAB.initStationList();
  my_DAB.printStationTable();
  my_DAB.initPresets();
  my_DAB.printPresetsTable();

  // initialize preset buttons
  init_preset();

  // initialize encoder
  init_KY040(); 

  // initialize Wifi
  if (LittleFS.exists("/ssid.txt")) ssid = readFile(LittleFS, "/ssid.txt");
  if (LittleFS.exists("/password.txt")) password = readFile(LittleFS, "/password.txt");

  bool connected = false;
  if ((ssid!="")&&(password!="")) {
    Serial.println("connecting with WiFi..");
    connected = connectWiFi();
  }
  if (!connected) accessPoint();

  // initialize web server user interface
  wi.begin(ssid, password); 

  // restore volume and station settings
  #ifdef digitalVolume
    if (LittleFS.exists("/volume.txt")) v_value = readFile(LittleFS, "/volume.txt").toInt();
    else v_value = 32;
    Serial.println("set volume to "+ (String)v_value);
    my_DAB.vol((uint8_t)v_value);
  #else
    v_value = 63;
    my_DAB.vol((uint8_t)v_value);
  #endif

  if (LittleFS.exists("/station.txt")) activePreset = readFile(LittleFS, "/station.txt").toInt();
  activeStation = my_DAB.presets[activePreset-1].number;
  my_DAB.tune(activeStation);
  Serial.println("tune to preset "+(String)activePreset+" = Station "+(String)activeStation);
}

void loop() {
  // check preset buttons
  int button = check_preset();
  if ((button!=0)&&(button!=activePreset)) {
    activePreset = button;
    Serial.println("preset button " + String(button));
    activeStation = my_DAB.presets[button-1].number;
    my_DAB.tune(activeStation);
    
    char buffer[10];  
    sprintf(buffer, "%d", button);
    writeFile(LittleFS, "/station.txt", buffer);
    Serial.println("save preset: "+(String)button);
  }

  #ifdef digitalVolume
    // check volume setting
    if (lastVol!=v_value) {
      lastVol = v_value;
      my_DAB.vol((uint8_t)v_value);
    
      char buffer[10];  
      sprintf(buffer, "%d", v_value);
      writeFile(LittleFS, "/volume.txt", buffer);
    }
  #endif

  // service web server and DAB radio
  my_DAB.task();
  wi.update();
}

//////////////////////////////////////////////////////////
//
//  preset buttons and volume control
//
//////////////////////////////////////////////////////////

void init_preset(){
  pinMode(preset1, INPUT);
  pinMode(preset2, INPUT);
  pinMode(preset3, INPUT);
  pinMode(preset4, INPUT);
  pinMode(preset5, INPUT);
  pinMode(preset6, INPUT);
}

int check_preset() {
  if (digitalRead(preset1) == HIGH) {
    return 1;
  } else if (digitalRead(preset2) == HIGH) {
    return 2;
  } else if (digitalRead(preset3) == HIGH) {
    return 3;
  } else if (digitalRead(preset4) == HIGH) {
    return 4;
  } else if (digitalRead(preset5) == HIGH) {
    return 5;
  } else if (digitalRead(preset6) == HIGH) {
    return 6; 
  }
  return 0; // no key pressed
}


//////////////////////////////////////////////////////////
//
//  KY040 Functions
//
//////////////////////////////////////////////////////////

void init_KY040() {
  pinMode(KY040_CLK, INPUT_PULLUP);
  pinMode(KY040_DT, INPUT_PULLUP);
  attachInterrupt(KY040_CLK, handleInterruptA, CHANGE);
  attachInterrupt(KY040_DT, handleInterruptB, CHANGE);
}


// ISR to handle pin change interrupt for D0 to D7 here
void IRAM_ATTR handleInterruptA() {
  long sysTime = micros();
    while ((micros()-sysTime)<1000) {}          // delay 1ms
    int currentA = digitalRead(KY040_CLK);
    if (currentA != lastA) {
      int increment = 1;
      if (v_value<50) increment = 2;
      if (v_value<40) increment = 3;
      if (v_value<25) increment = 5;
      if (v_value<15) increment = 10;
      if (currentA==HIGH) {            // A change: 1 => 0
        if (digitalRead(KY040_DT)==LOW) {
          v_value=v_value-increment;                       
          if (v_value<=0) v_value=0;
        }
        else {
          v_value=v_value+increment;                        
          if (v_value>=63) v_value=63;
        }
      } else {                        // A change: 0 => 1
        if (digitalRead(KY040_DT)==LOW) {
          v_value=v_value+increment;                        
          if (v_value>=63) v_value=63;
        } else {
          v_value=v_value-increment;                        
          if (v_value<=0) v_value=0;
        }
      }
      lastA = currentA;   
    }
}

void IRAM_ATTR handleInterruptB() {
}

//////////////////////////////////////////////////////////
//
//  system functions
//
//////////////////////////////////////////////////////////

bool connectWiFi() {
  WiFi.mode(WIFI_STA);
  WiFi.begin(ssid.c_str(), password.c_str());

  // Wait 20 seconds 
  unsigned long startAttemptTime = millis();
  const unsigned long timeout = 60000; 

  while (WiFi.status() != WL_CONNECTED) {
    if (millis() - startAttemptTime >= timeout) {
      Serial.println("Failed to connect to Wi-Fi within timeout period.");
      return false;
    }
    delay(500);
    Serial.print(".");
  }

  Serial.println("Connected to Wi-Fi.");
  Serial.print("IP Address: ");
  Serial.println(WiFi.localIP());
  return true;
}

void accessPoint() {
  Serial.println("Setting up Access Point...");
  WiFi.mode(WIFI_AP);
  if (!WiFi.softAP("mini_DAB", NULL)) {
    Serial.println("Failed to start Access Point.");
    return;
  }

  IPAddress apIP(192, 168, 4, 1);
  if (!WiFi.softAPConfig(apIP, apIP, IPAddress(255, 255, 255, 0))) {
    Serial.println("Failed to configure Access Point IP address.");
    return;
  }
  Serial.print("Access Point IP Address: ");
  Serial.println(WiFi.softAPIP());

  Serial.println("Access Point is active. Connect to the Wi-Fi network 'mini_DAB' without a password.");
}


//////////////////////////////////////////////////////////
//
//  SPI service function
//
//////////////////////////////////////////////////////////

void DABSpiMsg(unsigned char *data, uint32_t len)
{
  SPI.beginTransaction(SPISettings(2000000, MSBFIRST, SPI_MODE0));    //2MHz for starters...
  digitalWrite (my_DAB.slaveSelectPin, LOW);
  SPI.transfer(data, len);
  digitalWrite (my_DAB.slaveSelectPin, HIGH);
  SPI.endTransaction();
}

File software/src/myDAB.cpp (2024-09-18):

// =========================================================================================================================================
//                                                 Minimalist DAB+ radio
//                                                   © Ludwin Monz 2024
// License: Creative Commons Attribution - Non-Commercial - Share Alike (CC BY-NC-SA)
// you may use, adapt, share. If you share, "share alike".
// you may not use this software for commercial purposes 
// =========================================================================================================================================

#include <Arduino.h>
#include <ArduinoJson.h>
#include <WiFi.h>
#include <WebServer.h>
#include <SPI.h>
#include "myDAB.h"
#include "FileFunctions.h"
#include <LittleFS.h>

bool myDAB::_dabmode = true;
DAB myDAB::_Dab; 
int myDAB::_numberOfStations = 0;
String myDAB::_lastServiceData = "";
String myDAB::sInfo = "";

// =========================================================================================================================================
//                                                      Constructor
// =========================================================================================================================================

myDAB::myDAB() {
}

// =========================================================================================================================================
//                                                      begin Method:
// =========================================================================================================================================

void myDAB::begin() {
 
 //Enable SPI
  pinMode(slaveSelectPin, OUTPUT);
  digitalWrite(slaveSelectPin, HIGH);
  SPI.begin();

  Serial.print(F("Initialising DAB ==> ")); 

  //DAB Setup
  _Dab.setCallback(_ServiceData);
  _Dab.begin();

  if(_Dab.error != 0)
  {
    Serial.print(F("ERROR: "));
    Serial.print(_Dab.error);
    Serial.print(F("\nCheck DABShield is Connected and SPI Communications\n"));
  }
  else  
  {
    Serial.println("DABShield found"); 
  }
}

int myDAB::initStationList(){
  // read stationList
  if (LittleFS.exists("/stationList.json")) {
    _numberOfStations = readStationList();
    Serial.println("stationList read from file. Number of entries: "+String(_numberOfStations));
  }
  if ((!LittleFS.exists("/stationList.json"))||(_numberOfStations==0)) {
    Serial.println("No stationList found. Start scan.");
    _numberOfStations = scan();
    Serial.println("scan compete. Number of stations: " + String(_numberOfStations));
    if (saveStationList()) Serial.println("stationList saved successfully");
    else Serial.println("failed to save stationList");
  }
  return _numberOfStations;
}

void myDAB::task() {
  _Dab.task();
}

int myDAB::scan(){
  uint8_t freq_index;
  char freqstring[32];
  int stationIndex = 0;

  Serial.println("Starting scan....");
  Serial.println("===> number of DABfrequs = " + String(DAB_FREQS) + " <====");

  for (freq_index = 0; freq_index < DAB_FREQS; freq_index++)
  {
    Serial.print(".");
    _Dab.tune(freq_index);
    if(_Dab.servicevalid() == true)
    {

      for (int i = 0; i < _Dab.numberofservices; i++)
      {
        char channelInfo[128];

        _Dab.status(_Dab.service[i].ServiceID, _Dab.service[i].CompID);
        if(_Dab.type == SERVICE_AUDIO)
        {
          stationList[stationIndex].number = stationIndex;
          stationList[stationIndex].name = _Dab.service[i].Label;
          stationList[stationIndex].ensemble = (int)freq_index;
          stationList[stationIndex].serviceId = _Dab.service[i].ServiceID;
          stationList[stationIndex].compId = _Dab.service[i].CompID;
          stationIndex++;
        }
      }
    }
  }
  Serial.println("end of scan.");
  return stationIndex;
}

void myDAB::tune(int id) {
  uint8_t freq = (uint8_t)stationList[id].ensemble;
  uint32_t ServiceId = stationList[id].serviceId;
  uint32_t CompId = stationList[id].compId;

  _Dab.tuneservice(freq, ServiceId, CompId);
}

void myDAB::vol(uint8_t vol) {
  _Dab.vol(vol);
}

String myDAB::stationListJson() {
    // Create a static JSON document object.
    JsonDocument doc;
    JsonArray stationArray = doc.to<JsonArray>();

    // Loop through the stationList array and add each station to the JSON array
    for (int i = 0; i < _numberOfStations; i++) {
        JsonObject stationObj = stationArray.add<JsonObject>();
        stationObj["number"] = stationList[i].number;
        stationObj["name"] = stationList[i].name;
        stationObj["ensemble"] = stationList[i].ensemble;
        stationObj["serviceId"] = stationList[i].serviceId;
        stationObj["compId"] = stationList[i].compId;
    }

    // Serialize the JSON document into a string
    String output;
    serializeJson(doc, output);

    return output;
}

int myDAB::numberOfStations() {
  return _numberOfStations;
}   

bool myDAB::saveStationList() {
    String jsonString = stationListJson();
    return writeFile(LittleFS, "/stationList.json", jsonString.c_str());
}

int myDAB::readStationList() {
    File file = LittleFS.open("/stationList.json", FILE_READ);

    if (!file) {
        Serial.println("Failed to open /stationList.json");
        return 0; // return 0 on error
    }

    String jsonString;
    while (file.available()) {
        jsonString += file.readString();
    }
    file.close();

    JsonDocument doc;
    DeserializationError error = deserializeJson(doc, jsonString);

    // check if deserialization successful
    if (error) {
        Serial.println("Failed to deserialize JSON");
        return 0; // return 0 on error
    }

    JsonArray stationArray = doc.as<JsonArray>();

    int i = 0;
    for (JsonObject stationObj : stationArray) {
        stationList[i].number = stationObj["number"];
        stationList[i].name = stationObj["name"].as<String>();
        stationList[i].ensemble = stationObj["ensemble"];
        stationList[i].serviceId = stationObj["serviceId"];
        stationList[i].compId = stationObj["compId"];
        i++;
    }

    _numberOfStations = i;
    return _numberOfStations;
}

void myDAB::printStationTable() {

  Serial.println(F("----------------------------------------------------------"));
  Serial.println(F("| Number |    Station Name    | Ensemble |   ServiceId  |   CompId  |"));
  Serial.println(F("----------------------------------------------------------"));

  for (int i=0; i<_numberOfStations; i++) {
    // Formatierte Ausgabe
    Serial.printf("|   %-5d| %-18s|   %-7d|   %-10d|   %-10d|\n", stationList[i].number, stationList[i].name.c_str(), stationList[i].ensemble, stationList[i].serviceId, stationList[i].compId);
  }

  Serial.println(F("----------------------------------------------------------"));
}
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

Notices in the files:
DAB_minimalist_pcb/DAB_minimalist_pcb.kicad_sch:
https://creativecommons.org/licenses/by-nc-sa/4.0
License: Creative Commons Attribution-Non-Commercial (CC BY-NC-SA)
